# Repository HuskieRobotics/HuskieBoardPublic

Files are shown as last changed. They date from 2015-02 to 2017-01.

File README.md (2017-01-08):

# The Huskie Board
## Overview
The Huskie Board, designed by Team 3061, is an FRC qualified expansion board for the
NI roboRIO robotics controller. In addition to breaking out all available signals on the
MXP expansion port, this board uses a Parallax Propeller chip (8 symmetrical logical
cores with shared memory and peripheral access) to enable tasks such as advanced
data logging, on-field driver control and status, and NeoPixel control. Additional GPIO
and analog inputs are added with open source code to allow further customization.

## Firmware
The Huskie Board's firmware is stored on a 32 KB Flash chip. It can be upgraded over USB, and teams are welcome to load their own firmware. All Huskie Board firmware is stored in the `propeller firmware/` directory.

## roboRIO software
The LabView firmware is available in the `LabView/LabVIEW API/` directory. This includes examples in the `Examples/` folder, and the API source code in the `Huskie Board/` folder. See `install.txt` for more information.

Currently, the roboRIO API is only available for labview, though we hope to port it for C++ and Java soon.

## Hardware
The Huskie Board was designed in Eagle CAD, and sources are available in `Eagle CAD/projects/HuskieBoard/`.

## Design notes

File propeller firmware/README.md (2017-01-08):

# Huskie Board Firmware

---

### Language
The Huskie Board runs on the [Parallax Propeller microcontroller](https://www.parallax.com/catalog/microcontrollers/propeller/chips). The majority of our code is written in Spin, though there is some pasm (assembly) included. The development environment is available [here](https://www.parallax.com/downloads/propeller-tool-software-windows). 

---

### Object Heiarchy
* `main.spin`
  * `RR uart connection.spin`
    * `FASTSERIAL-080927.spin`
    * `adc124s021_x2.spin`
    * `Disabled Parallax Serial Terminal.spin`
    * `Serial_Lcd.spin`
      * `Simple_Serial.spin`
    * `LED Main.spin`
      * `Neopixel Driver.spin`
    * `SD Controller.spin`
      * `fsrw.spin`
        * `safe_spi.spin`
---
### File Descriptions

`Disabled Parallax Serial Terminal.spin` - Allows us to turn off the debugging software for release versions. `Parallax Serial Terminal.spin` can be used instead to enable debugging.

`FASTSERIAL-080927.spin` - Used to communicate with the RoboRio at a high baud rate.

`fsrw.spin` - FAT32 filesystem control for the SD card

`adc124s021_x2.spin` - Controls SPI communication with the onboard ADCs, as well as averaging of the ADC values.

`LED Main.spin` - Controls a strip of Neopixel LEDs on the robot. The patterns can be selected by the RoboRIO. More patterns can be added here.

`main.spin` - Top object file, initiates all processes. Also controls the 4 LEDs to indicate DIP switch positions.

`Neopixel Driver.spin` - Neopixel LED driver

`ProductionTesterWithMain.spin` - Used to test each Huskie Board on a custom fixture before shipping. This is technically what is on the Huskie Board when it is purchased, but if firmware needs to be reflashed by a user, they should flash `main.spin`.

`Propeller EEprom.spin` - Dependancy of `ProductionTesterWithMain.spin`, allows for saving data to the EEprom for permanent storage.

`RR uart connection.spin` - UART controller for connection between propeller and roboRIO

`safe_spi.spin` - SPI routines used for the SD card

`SD Controller.spin` - High level API for SD card control

`Serial_Lcd.spin` - High level interface for Parallax LCD displays

`Simple_Serial.spin` - A simple low baud rate serial object, for use with the LCD displays.
---

# How To Load Code
1. Run the Propeller Tool executable
2. Open "main.spin"
3. Compile and load to EEPROM (Run -> Compile Current -> Load EEPROM)

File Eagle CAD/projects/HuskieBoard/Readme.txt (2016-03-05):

Fab Drawing                    | Fab.pdf
Assy Drawing                   | Assy.pdf
Fab Array Drawing, no holes    | Fab_1x3A.pdf
Fab Array Drawing, with holes  | Fab_1x3B.pdf

Top Copper                     | RoboRIO Expansion Board V2.GTL
Bottom Copper                  | RoboRIO Expansion Board V2.GBL
Top Silkscreen                 | RoboRIO Expansion Board V2.GTO
Top Paste                      | RoboRIO Expansion Board V2.GTP
Top Soldermask                 | RoboRIO Expansion Board V2.GTS
Bottom Soldermask              | RoboRIO Expansion Board V2.GBS
Drill File                     | RoboRIO Expansion Board V2.TXT
Mill Layer                     | RoboRIO Expansion Board V2.GML

centroid file                  | RoboRIO Expansion Board V2_centroid.csv

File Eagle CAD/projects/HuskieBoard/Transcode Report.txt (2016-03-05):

   ---- Transcoding 'C:\Users\d_emge\Documents\GitHub\roborioExpansion\projects\RoboRio\RoboRioExpansionBoard\RoboRio Expansion Board V2.GTP' ----   Wed Feb 03 08:32:43 2016

D10   --> D356
D11   --> D357
D12   --> D358
D13   --> D359
D14   --> D360
D15   --> D361
D16   --> D362
D17   --> D363
D18   --> D364
D19   --> D365
D20   --> D366
D21   --> D367
D22   --> D368
D23   --> D369
D24   --> D370
D25   --> D371
D26   --> D372
D27   --> D373
D28   --> D374
D29   --> D375
D30   --> D376
D31   --> D377
-----------------------------------------------------------------

   ---- Transcoding 'C:\Users\d_emge\Documents\GitHub\roborioExpansion\projects\RoboRio\RoboRioExpansionBoard\RoboRio Expansion Board V2.GTS' ----   Wed Feb 03 08:32:43 2016

D10   --> D378
D11   --> D379
D12   --> D380
D13   --> D381
D14   --> D382
D15   --> D383
D16   --> D384
D17   --> D385
D18   --> D386
D19   --> D387
D20   --> D388
D21   --> D389
D22   --> D390
D23   --> D391
D24   --> D392
D25   --> D393
D26   --> D394
D27   --> D395
D28   --> D396
D29   --> D397
D30   --> D398
D31   --> D399
D32   --> D400
D33   --> D401
D34   --> D402
D35   --> D403
D36   --> D404
D37   --> D405
D39   --> D406
D40   --> D407
D41   --> D408
-----------------------------------------------------------------

   ---- Transcoding 'C:\Users\d_emge\Documents\GitHub\roborioExpansion\projects\RoboRio\RoboRioExpansionBoard\RoboRio Expansion Board V2.GTL' ----   Wed Feb 03 08:32:43 2016

D10   --> D409
D11   --> D410
D12   --> D411
D13   --> D412
D14   --> D413
D15   --> D414
D16   --> D415
D17   --> D416
D18   --> D417
D19   --> D418
D20   --> D419
D21   --> D420
D22   --> D421
D23   --> D422
D24   --> D423
D25   --> D424
D26   --> D425
D27   --> D426
D28   --> D427
D29   --> D428
D30   --> D429
D31   --> D430
D32   --> D431
D33   --> D432
D34   --> D433
D35   --> D434
D36   --> D435
D37   --> D436
D39   --> D437
D40   --> D438
D41   --> D439
D42   --> D440
D43   --> D441
D44   --> D442
D45   --> D443
D46   --> D444
D47   --> D445
D48   --> D446
D49   --> D447
D50   --> D448
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
-----------------------------------------------------------------

   ---- Transcoding 'C:\Users\d_emge\Documents\GitHub\roborioExpansion\projects\RoboRio\RoboRioExpansionBoard\RoboRio Expansion Board V2.GBL' ----   Wed Feb 03 08:32:43 2016

D11   --> D451
D12   --> D452
D13   --> D453
D14   --> D454
D15   --> D455
D16   --> D456
D17   --> D457
D18   --> D458
D19   --> D459
D20   --> D460
D21   --> D461
D22   --> D462
D23   --> D463
D24   --> D464
-----------------------------------------------------------------

   ---- Transcoding 'C:\Users\d_emge\Documents\GitHub\roborioExpansion\projects\RoboRio\RoboRioExpansionBoard\RoboRio Expansion Board V2.GBS' ----   Wed Feb 03 08:32:43 2016

D10   --> D465
D11   --> D466
D12   --> D467
D13   --> D468
D14   --> D469
D15   --> D470
D16   --> D471
D17   --> D472
D18   --> D473
-----------------------------------------------------------------

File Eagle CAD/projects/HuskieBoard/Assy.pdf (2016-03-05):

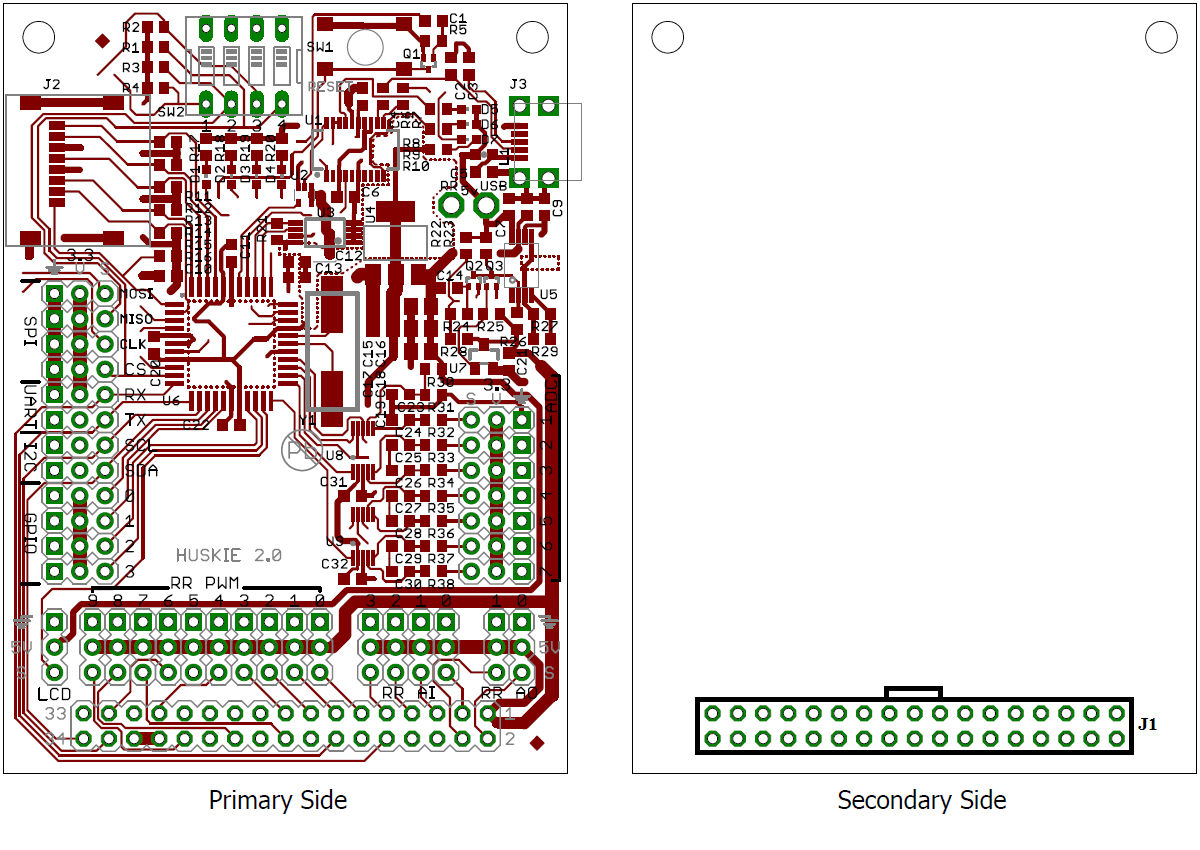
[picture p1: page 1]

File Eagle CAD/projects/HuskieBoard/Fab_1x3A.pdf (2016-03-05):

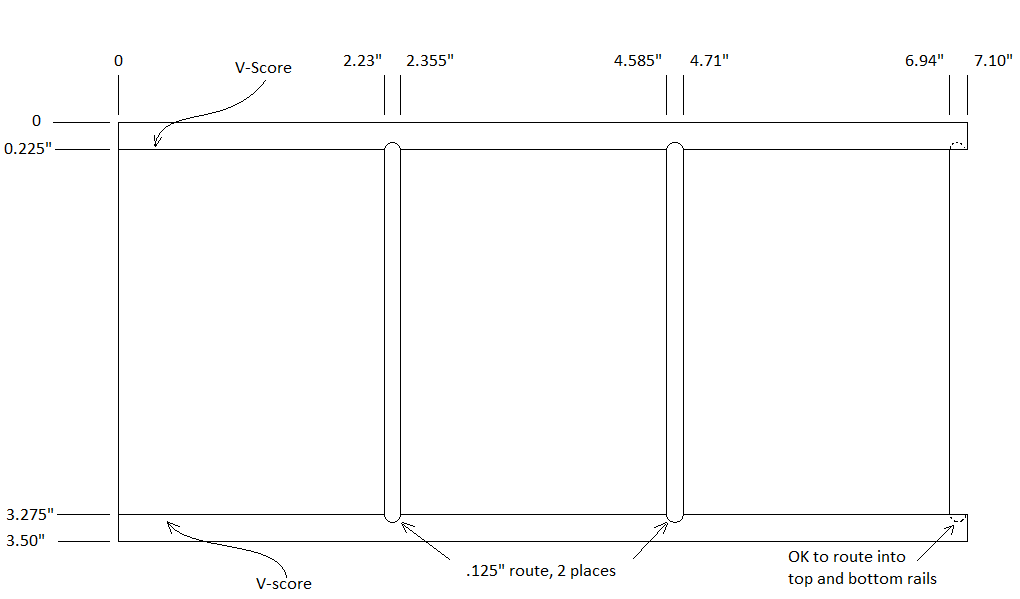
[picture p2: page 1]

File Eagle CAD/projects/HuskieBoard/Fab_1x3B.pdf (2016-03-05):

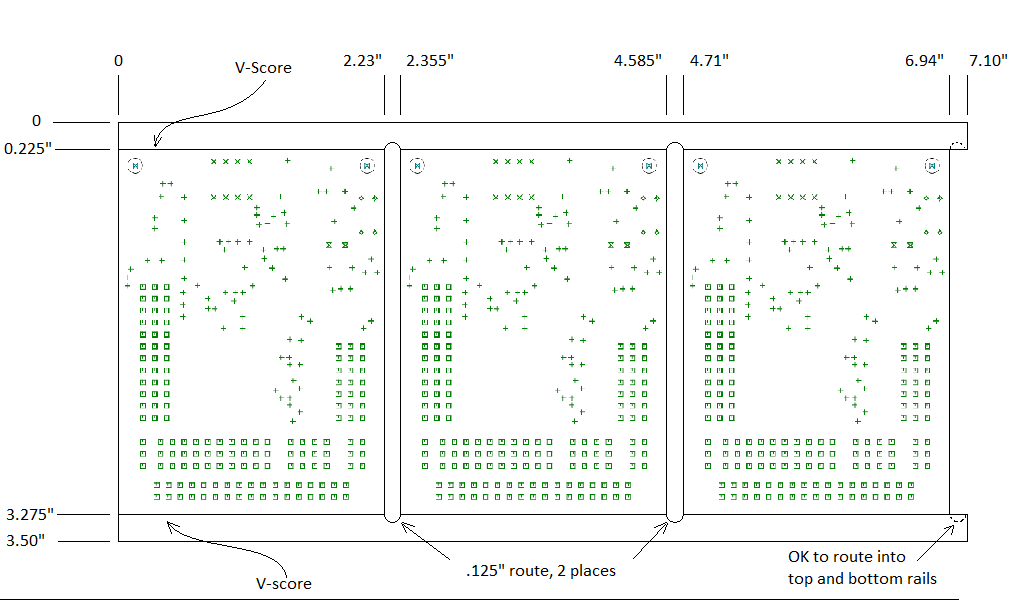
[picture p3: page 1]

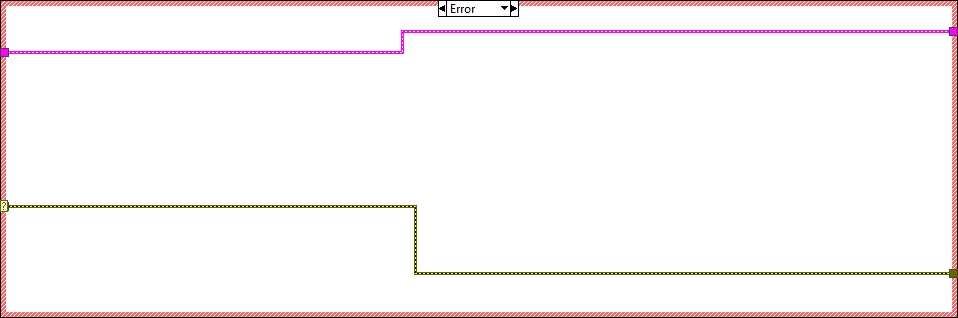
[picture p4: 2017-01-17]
LabView/LabVIEW API/Huskie Board/HuskieBoard API Doc/HB_GetFirmwareVersion/HB__GetFirmwareVersiond2.png

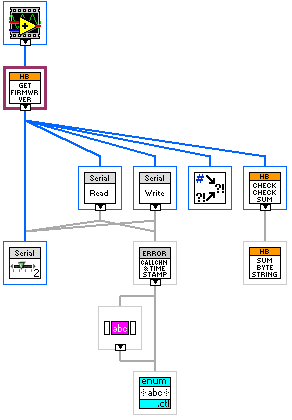
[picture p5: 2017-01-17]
LabView/LabVIEW API/Huskie Board/HuskieBoard API Doc/HB_GetFirmwareVersion/HB__GetFirmwareVersionh.png

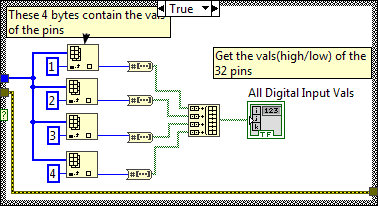
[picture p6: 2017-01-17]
LabView/LabVIEW API/Huskie Board/HuskieBoard API Doc/HB_ReadDIOAllChannels/HB__ReadDIOAllChannelsd1.png

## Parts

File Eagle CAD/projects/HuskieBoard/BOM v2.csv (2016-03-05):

Qty | Value | Device | Package | Parts | Description | MF | MPN | OC_FARNELL | OC_NEWARK | TP_SIGNAL_NAME
12 |  | 3PINDEVICEDEFAULT | 3PINPACKAGE | J4, J5, J6, J7, J11, J17, J18, J19, J20, J21, J22, J23
1 |  | SW_DIP-4 | EDG-04 | SW1 | DIP SWITCH
7 | .1uF | C-EUC0603K | C0603K | C1, C2, C3, C6, C10, C13, C17 | CAPACITOR, European symbol
8 | 0.1uF | C-EUC0603K | C0603K | C14, C15, C16, C19, C21, C22, C23, C24 | CAPACITOR, European symbol
18 | 10k | R-US_R0603 | R0603 | R1, R3, R6, R7, R8, R15, R16, R17, R18, R19, R23, R29, R30, R31, R32, R33, R34, R35 | RESISTOR, American symbol
6 | 10uF | C-EUC0805K | C0805K | C4, C5, C7, C11, C12, C20 | CAPACITOR, European symbol
3 | 1k | R-US_R0603 | R0603 | R5, R13, R14 | RESISTOR, American symbol
3 | 1uF | C-EUC0603K | C0603K | C8, C9, C18 | CAPACITOR, European symbol
5 | 220 | R-US_R0603 | R0603 | R4, R9, R10, R11, R12 | RESISTOR, American symbol
1 | 24LC256ST | 24LC128ST | TSSOP8 | U2 | Serial EEPROM | MICROCHIP | 24LC128-I/ST | 1296573 | 62K0578
8 | 270 | R-US_R0603 | R0603 | R2, R20, R21, R22, R24, R25, R26, R28 | RESISTOR, American symbol
1 | 33k | R-US_R0603 | R0603 | R27 | RESISTOR, American symbol
1 | 51387-0578 | USBMINIB | USB-MINIB | J3 | USB Connectors
2 | ADC124S01 | ADC124S01 | ADC124S021VSSOP | U$1, U$2
1 | AI0 | 3PINDEVICEDEFAULT | 3PINPACKAGE | J35
1 | AI1 | 3PINDEVICEDEFAULT | 3PINPACKAGE | J36
1 | AI2 | 3PINDEVICEDEFAULT | 3PINPACKAGE | J37
1 | AI3 | 3PINDEVICEDEFAULT | 3PINPACKAGE | J38
1 | AO0 | 3PINDEVICEDEFAULT | 3PINPACKAGE | J39
1 | AO1 | 3PINDEVICEDEFAULT | 3PINPACKAGE | J40
1 | BLUE | LEDCHIPLED_0603 | CHIPLED_0603 | D6 | LED
1 | BUTTON | BUTTON | RESETBUTTON300000MILLION | S1
1 | FT232RL | FT232RL | SSOP28 | U3 | Source: http://www.ftdichip.com/Documents/DataSheets/DS_FT232R_v104.pdf |  | FT232RL | 1146032 | 91K9918
2 | GREEN | LEDCHIPLED_0603 | CHIPLED_0603 | D1, D4 | LED
1 | HC\49USCRYSTAL | HC\49USCRYSTAL | HC\49US | Y1
1 | I2C_SCL | 3PINDEVICEDEFAULT | 3PINPACKAGE | J12
1 | I2C_SDA | 3PINDEVICEDEFAULT | 3PINPACKAGE | J13
1 | LCD | 3PINDEVICEDEFAULT | 3PINPACKAGE | J16
1 | MICROSD-HINGED | MICROSD-HINGED | MICRO_SD_HINGED_TYPE | J2
3 | NPN-SOT416 | NPN-SOT416 | SC75_INFINEON | Q1, Q2, Q3
1 | P8X32A-Q44_P | P8X32A-Q44_P | P8X32A-Q44 | U1
1 | PWM0 | 3PINDEVICEDEFAULT | 3PINPACKAGE | J25
1 | PWM1 | 3PINDEVICEDEFAULT | 3PINPACKAGE | J26
1 | PWM2 | 3PINDEVICEDEFAULT | 3PINPACKAGE | J27
1 | PWM3 | 3PINDEVICEDEFAULT | 3PINPACKAGE | J28
1 | PWM4 | 3PINDEVICEDEFAULT | 3PINPACKAGE | J29
1 | PWM5 | 3PINDEVICEDEFAULT | 3PINPACKAGE | J30
1 | PWM6 | 3PINDEVICEDEFAULT | 3PINPACKAGE | J31
1 | PWM7 | 3PINDEVICEDEFAULT | 3PINPACKAGE | J32
1 | PWM8 | 3PINDEVICEDEFAULT | 3PINPACKAGE | J33
1 | PWM9 | 3PINDEVICEDEFAULT | 3PINPACKAGE | J34
2 | RED | LEDCHIPLED_0603 | CHIPLED_0603 | D3, D5 | LED
1 | REG1117 | REG1117 | SOT223 | U7 | 800mA and 1A Low Dropout (LDO) Positive Regulator |  | AP1117 | 1097566 | 14P6981
1 | RRINTERFACE-FEMALE | RRINTERFACE-FEMALE | RRINT-FEMALE | J1
1 | SPI_CLK | 3PINDEVICEDEFAULT | 3PINPACKAGE | J9
1 | SPI_CS | 3PINDEVICEDEFAULT | 3PINPACKAGE | J8
1 | SPI_MISO | 3PINDEVICEDEFAULT | 3PINPACKAGE | J10
1 | TC54-CB | TC54-CB | SOT23 | U4 | Microchip TC54 Voltage Detector
2 | TPPAD1-17 | TPPAD1-17 | P1-17 | TP_5V-RR, TP_5V-USB | Test pad
1 | TPS2115APWR | TPS2115APWR | TSSOP-8 | U6
1 | TP_GND | 3PINDEVICEDEFAULT | 3PINPACKAGE | J24
1 | UART_RX | 3PINDEVICEDEFAULT | 3PINPACKAGE | J15
1 | UART_TX | 3PINDEVICEDEFAULT | 3PINPACKAGE | J14
1 | YELLOW | LEDCHIPLED_0603 | CHIPLED_0603 | D2 | LED

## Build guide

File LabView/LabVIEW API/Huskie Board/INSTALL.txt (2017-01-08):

Huskie Board LabVIEW SDK Installation Instructions

The installer for the Huskie Board LabVIEW SDK is coming soon. In the
	meantime, the SDK has to be installed manually.

1. Unzip the downloaded zip file.
2. Copy the Huskie Board folder into the vi.lib\Rock
	Robotics\WPI\ThirdParty\Sensors folder in the LabVIEW 2016
	folder. By default, the full path is C:\Program Files\National
	Instruments\LabVIEW 2016\vi.lib\Rock
	Robotics\WPI\ThirdParty\Sensors\
3. Copy the HB-errors.txt file into the user.lib\errors folder in the
	LabVIEW 2016 folder. By default, the full path is C:\Program
	Files\National Instruments\LabVIEW
	2016\user.lib\errors\HB-errors.txt
4. The Examples folder may be copied anywhere that is convenient.

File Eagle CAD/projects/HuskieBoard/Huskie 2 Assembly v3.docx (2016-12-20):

# Huskie 2.0

# Assembly Instructions

# Version 3, 4/26/2016

Assembly Instructions Version | Date | Changed by | Reason for change
1 | 2/8/2016 | D. Emge | Original, prototype build
2 | x | x | Intentionally skipped to sync assy and BOM versions
3 | 4/26/2016 | D. Emge | Fix power supply oscillation, pilot build. Add section 5, rework instructions for converting from version1 to version 3.

1. General Information
  1.1. This is a lead-free assembly.
2. Surface Mount Assembly

Please reference Figure 1.

  2.1. The following parts are not installed:
- C14, C15, C17
  2.2. LEDs D1 through D4 are installed with Anodes at the bottom and Cathodes at the top. Cathodes are marked with a silkscreen dot.
  2.3. LEDs D5 through D7 are installed with Anodes on the right and Cathodes on the left.

Cathodes are marked with a silkscreen dot.

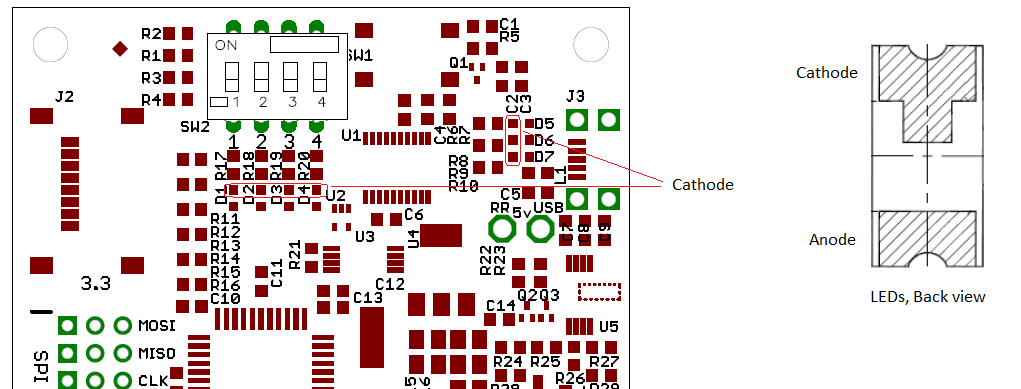
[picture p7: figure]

Figure 1, SW2 and LED Orientation

3. PTH Assembly – Primary Side
  3.1. SW2 is installed with the orientation shown in Figure 1, above, with the switch numbering aligned with the board’s silkscreen number markings.
  3.2. Header pins are arranged in sets of 3. Pins must be parallel in final assembly to allow proper connection of individual 3-pin mating connectors (each square pin is pin 1 of a 3-pin connection). Use a jig if necessary to maintain parallelism.

There are qyt 3 36-pin header strips on the BOM. They are separated into smaller headers as follows for installation on the PCB.

    3.2.1. Header strip 1: Separate into qty 3 12-pin strips and install in Location

A

    3.2.2. Header strip 2:
- Separate into qty 3 10-pin headers and install in Location

B

- Separate the remainder into qty 2 3-pin headers and install in location

C

    3.2.3. Header strip 3:
- Separate into qty 3 7-pin headers and install in Location

D

- Separate from the remainder qty 3 4-pin headers and install in Location

E

- Install the remaining 1x3 pin header into Location

F

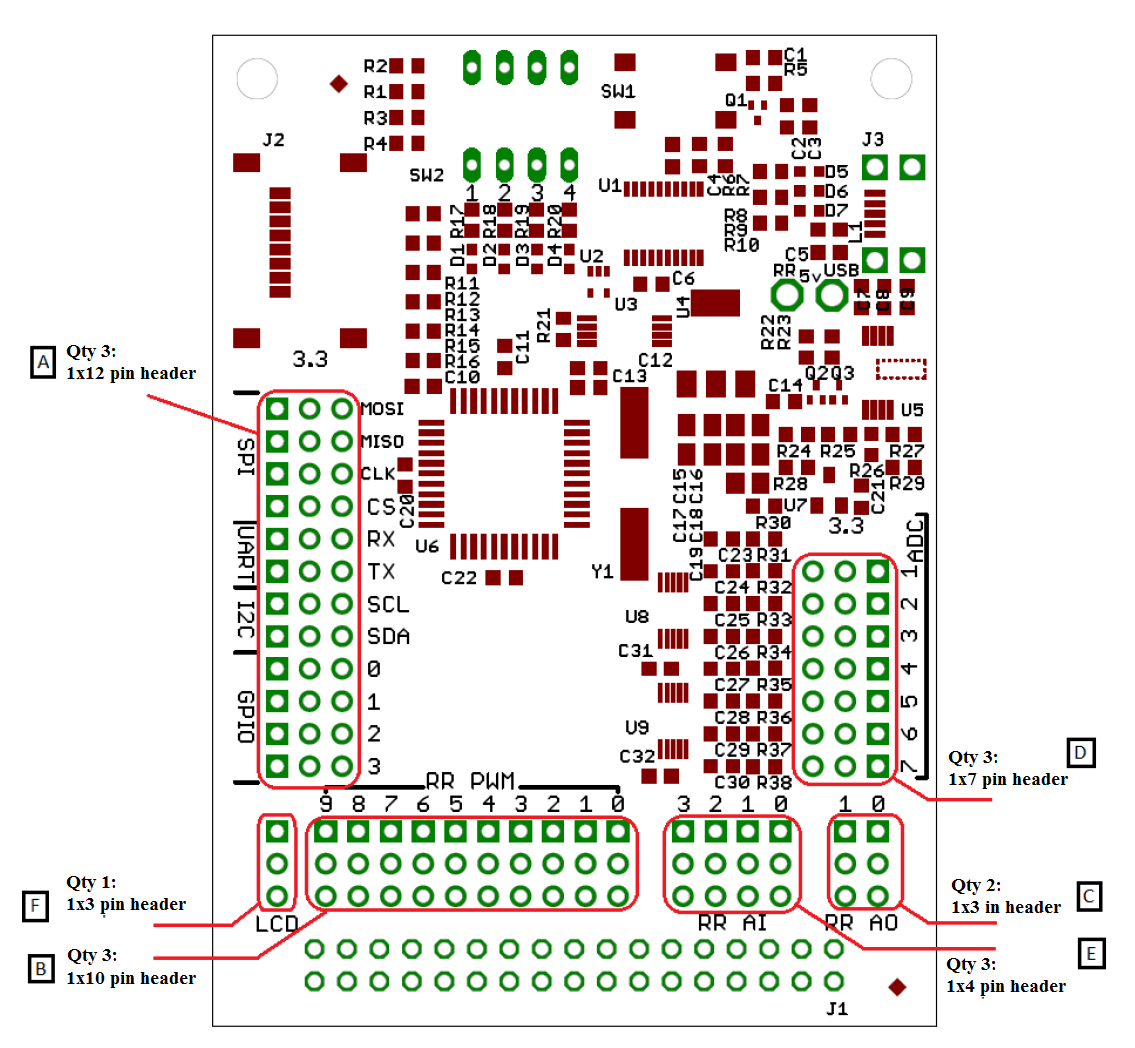
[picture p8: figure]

Figure 2, Header Placement

4. PTH Assembly – Secondary Side

J1 is installed on the secondary with the key oriented as shown below. It must be installed perpendicular to and flush with the PCB.

5. Rework Instructions, Version 1 to Version 3

For new builds, ignore this section.

  5.1. Remove capacitors C15 and C17.
  5.2. Remove U4 and replace with device indicated on BOM version 3.

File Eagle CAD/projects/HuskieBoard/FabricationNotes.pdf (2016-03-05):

1. Material
1.1. All material to be RoHS compliant.
1.2. All material to be tolerant of Pb-free solder process temperatures.
1.3. All material, including solder mask and legends, shall have a UL flammability rating of 94V-0. Date code and manufacturers UL symbol/type shall be permanently marked or etched on the board.
2. Solder Mask
2.1. Solder mask both sides, with blue color.
2.2. Encroach primary side via pads but prevent solder mask in via holes.
2.3. No solder mask on secondary side via pads.
2.4. No solder mask on component pads
2.5. Solder mask must be present between adjacent SMT pads.
3. Silkscreen
3.1. No silkscreen allowed on exposed lands or in holes.

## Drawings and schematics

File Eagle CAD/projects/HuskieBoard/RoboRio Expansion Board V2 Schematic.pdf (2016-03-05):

# CBUS3 19 CBUS2 10 CBUS1 17 CBUS0 18 RI 5 DCD 8 DSR 7 DTR 1 CTS 9 RTS 2

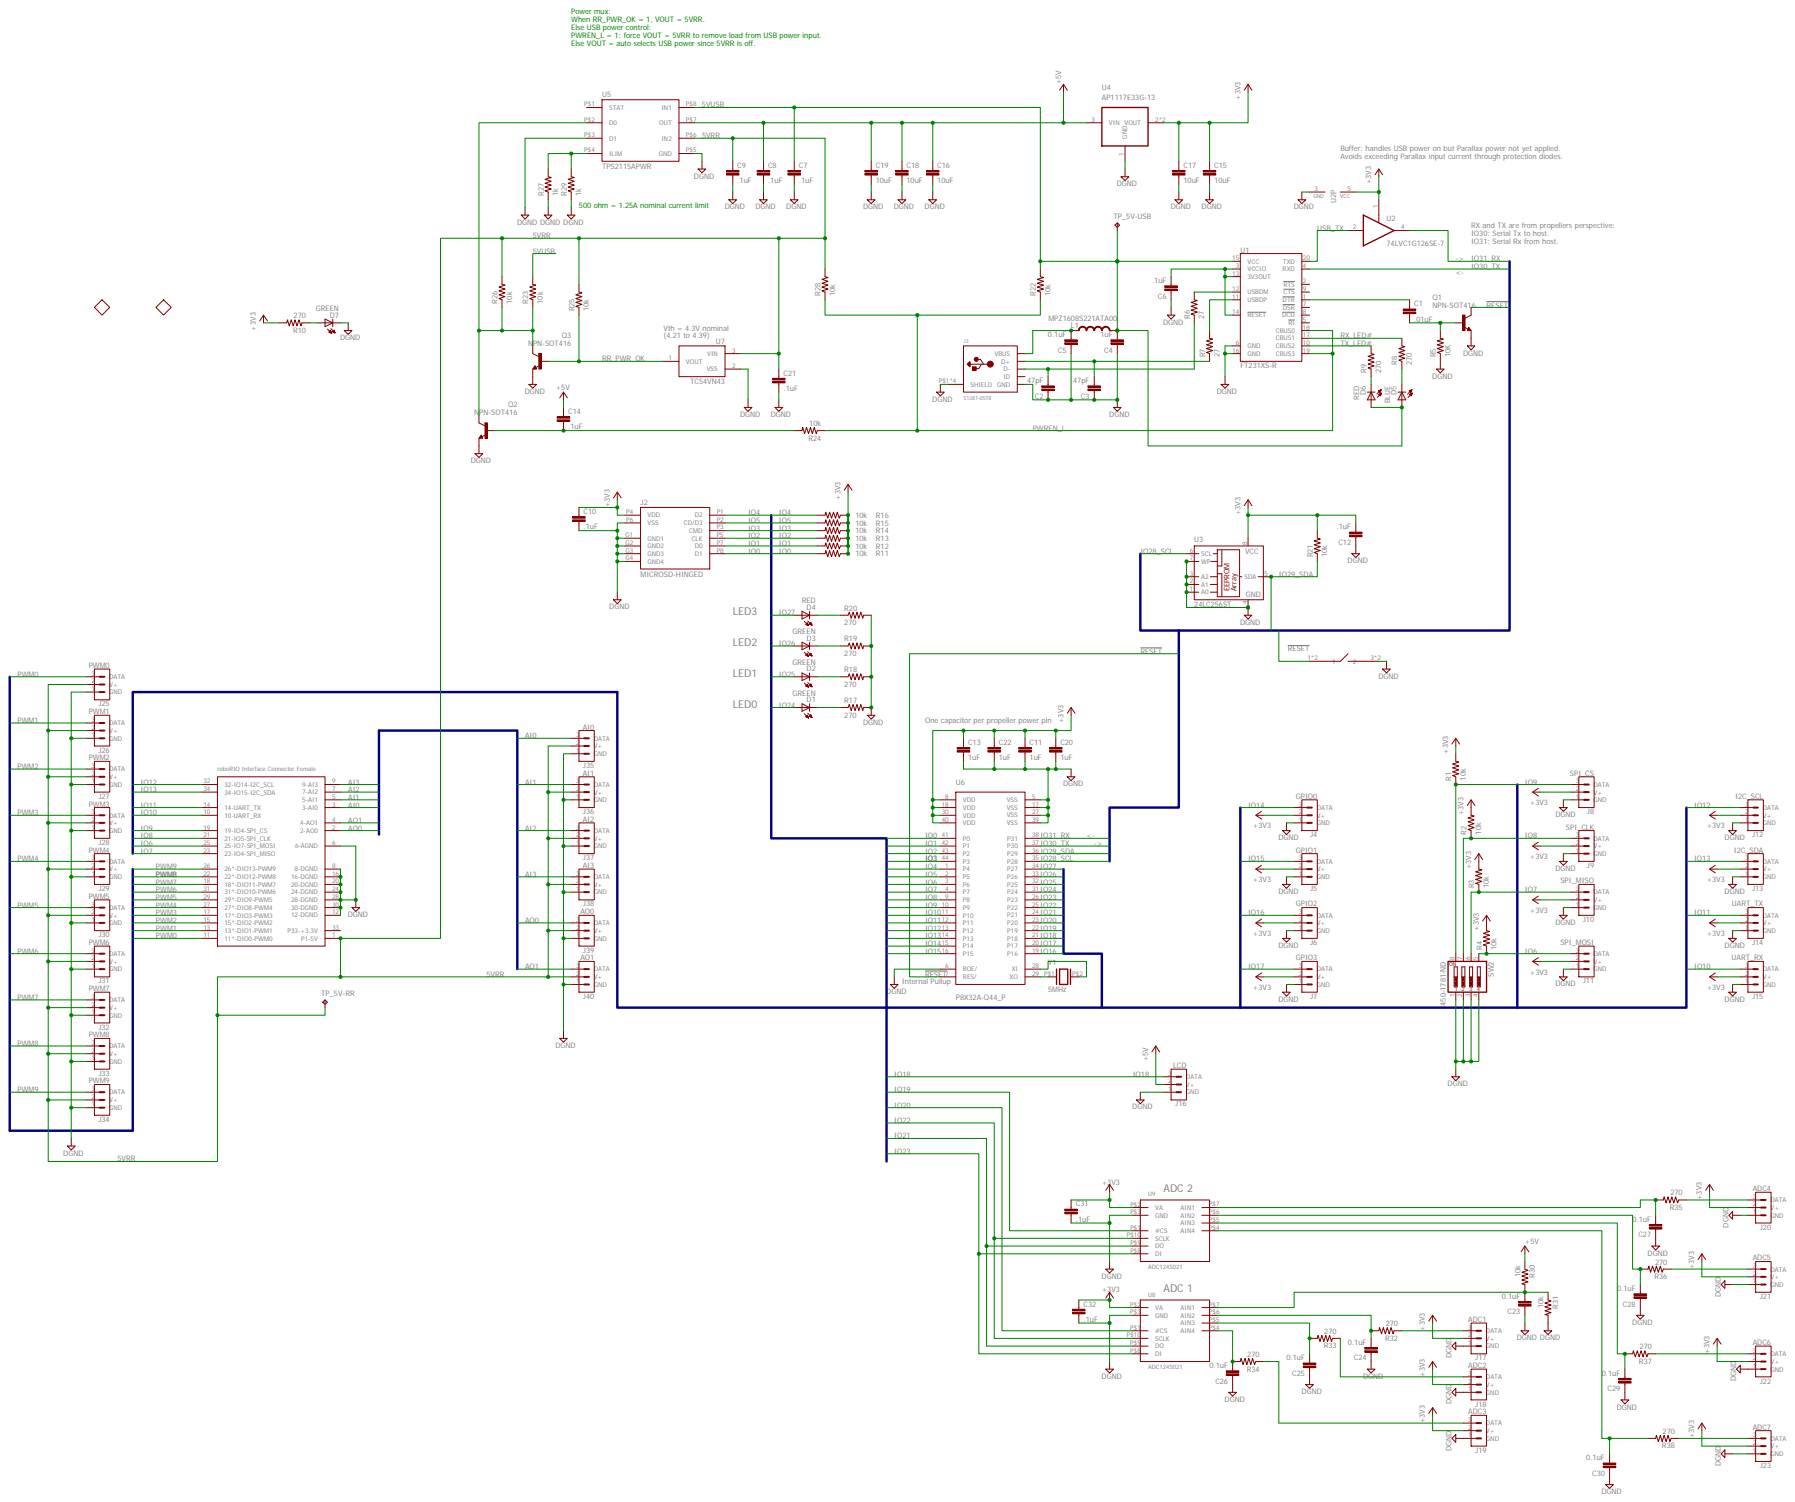
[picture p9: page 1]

Power mux:
When RR_PWR_OK = 1, VOUT = 5VRR.
Else USB power control:
PWREN_L = 1: force VOUT = 5VRR to remove load from USB power input.
Else VOUT = auto selects USB power since 5VRR is off.

Buffer: handles USB power on but Parallax power not yet applied.
Avoids exceeding Parallax input current through protection diodes.

500 ohm = 1.25A nominal current limit

RX and TX are from propellers perspective:
IO30: Serial Tx to host.
IO31: Serial Rx from host.

One capacitor per propeller power pin

roboRIO Interface Connector Female

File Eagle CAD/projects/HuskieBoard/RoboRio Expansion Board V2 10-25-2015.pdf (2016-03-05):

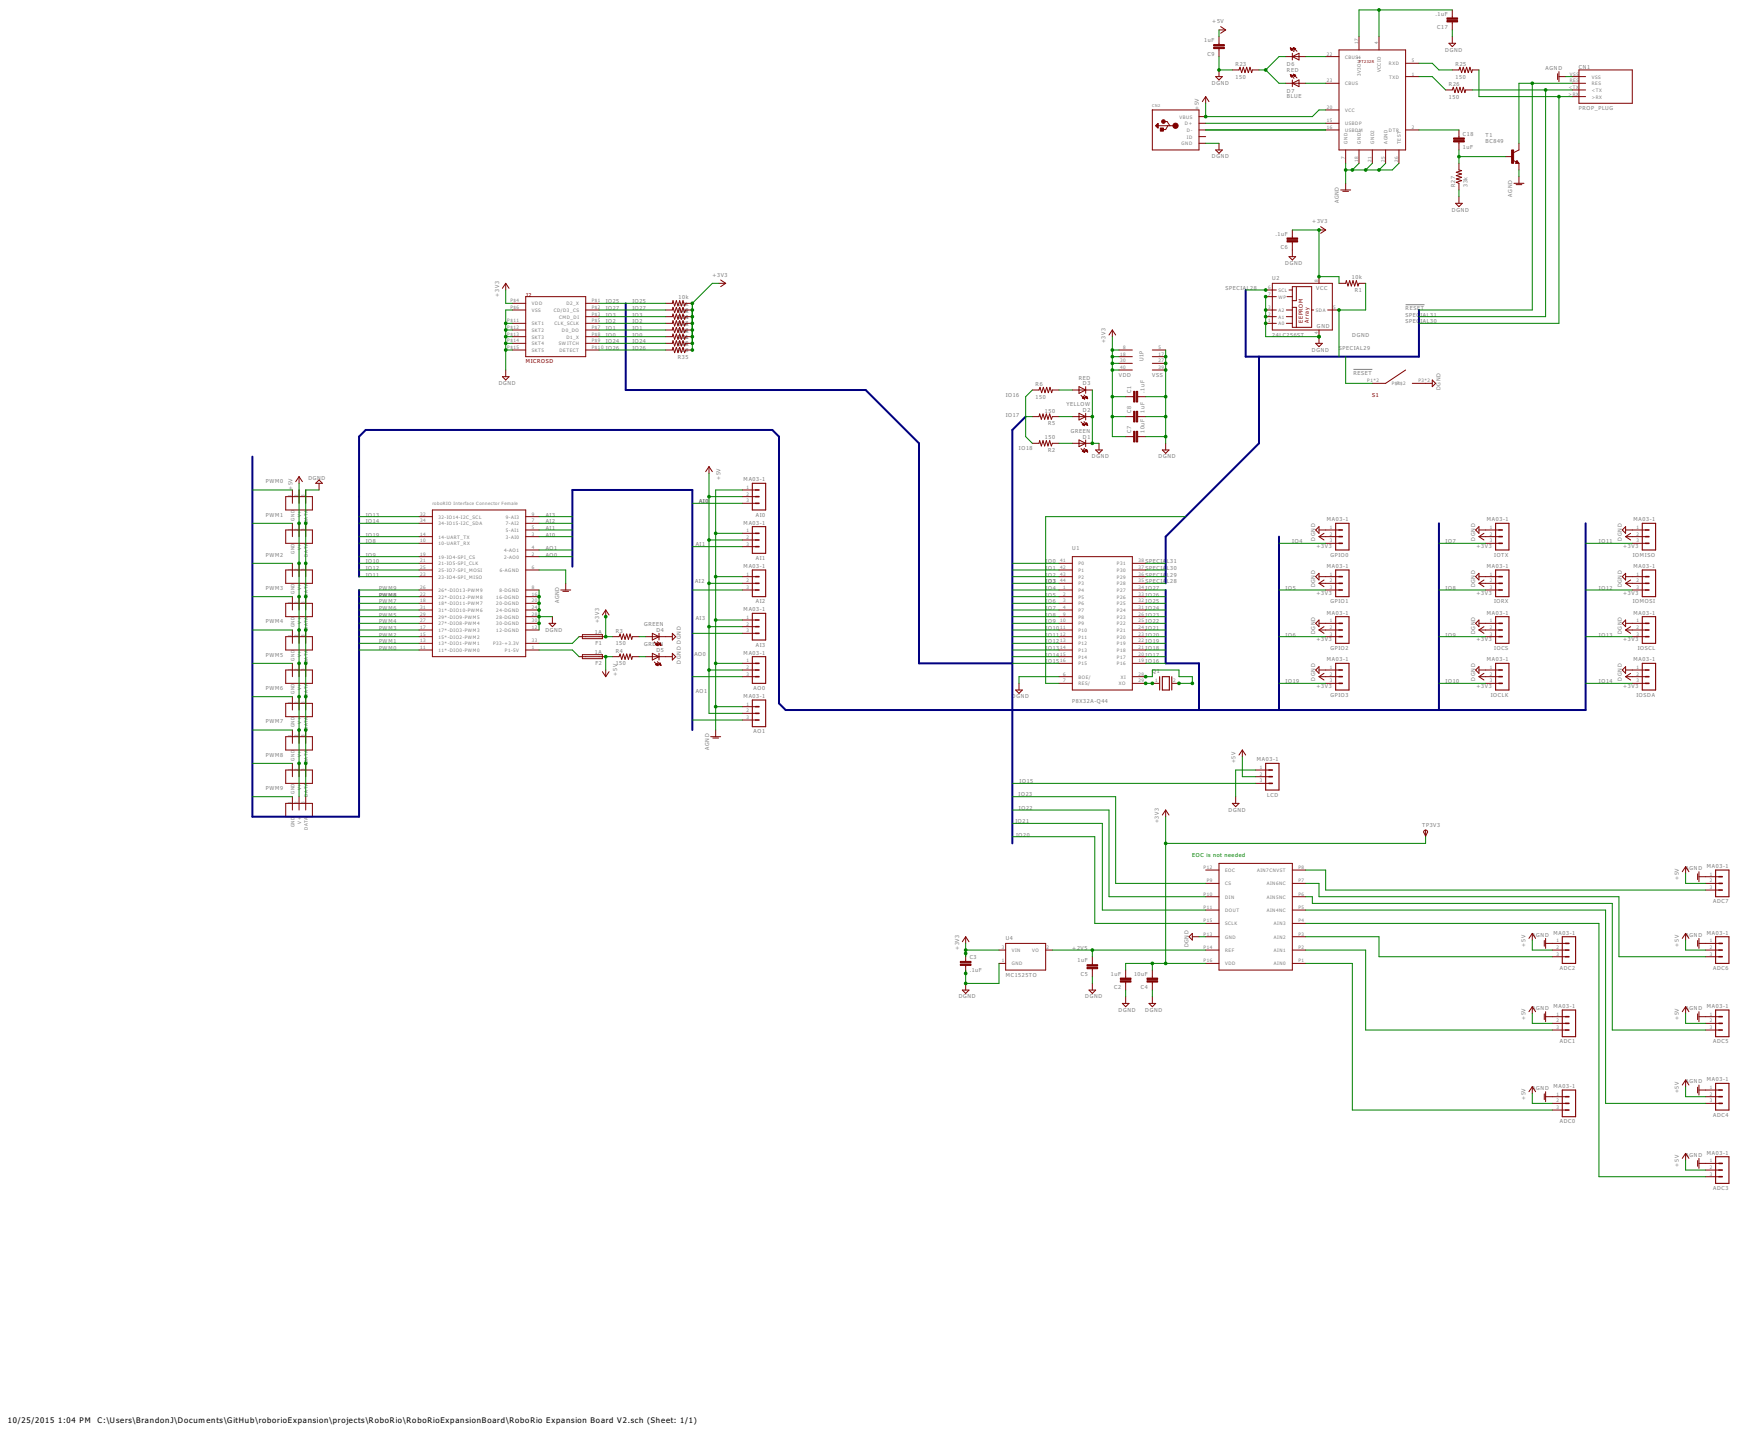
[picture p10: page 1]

roboRIO Interface Connector Female

EOC is not needed

10/25/2015 1:04 PM C:\Users\BrandonJ\Documents\GitHub\roborioExpansion\projects\RoboRio\RoboRioExpansionBoard\RoboRio Expansion Board V2.sch (Sheet: 1/1)

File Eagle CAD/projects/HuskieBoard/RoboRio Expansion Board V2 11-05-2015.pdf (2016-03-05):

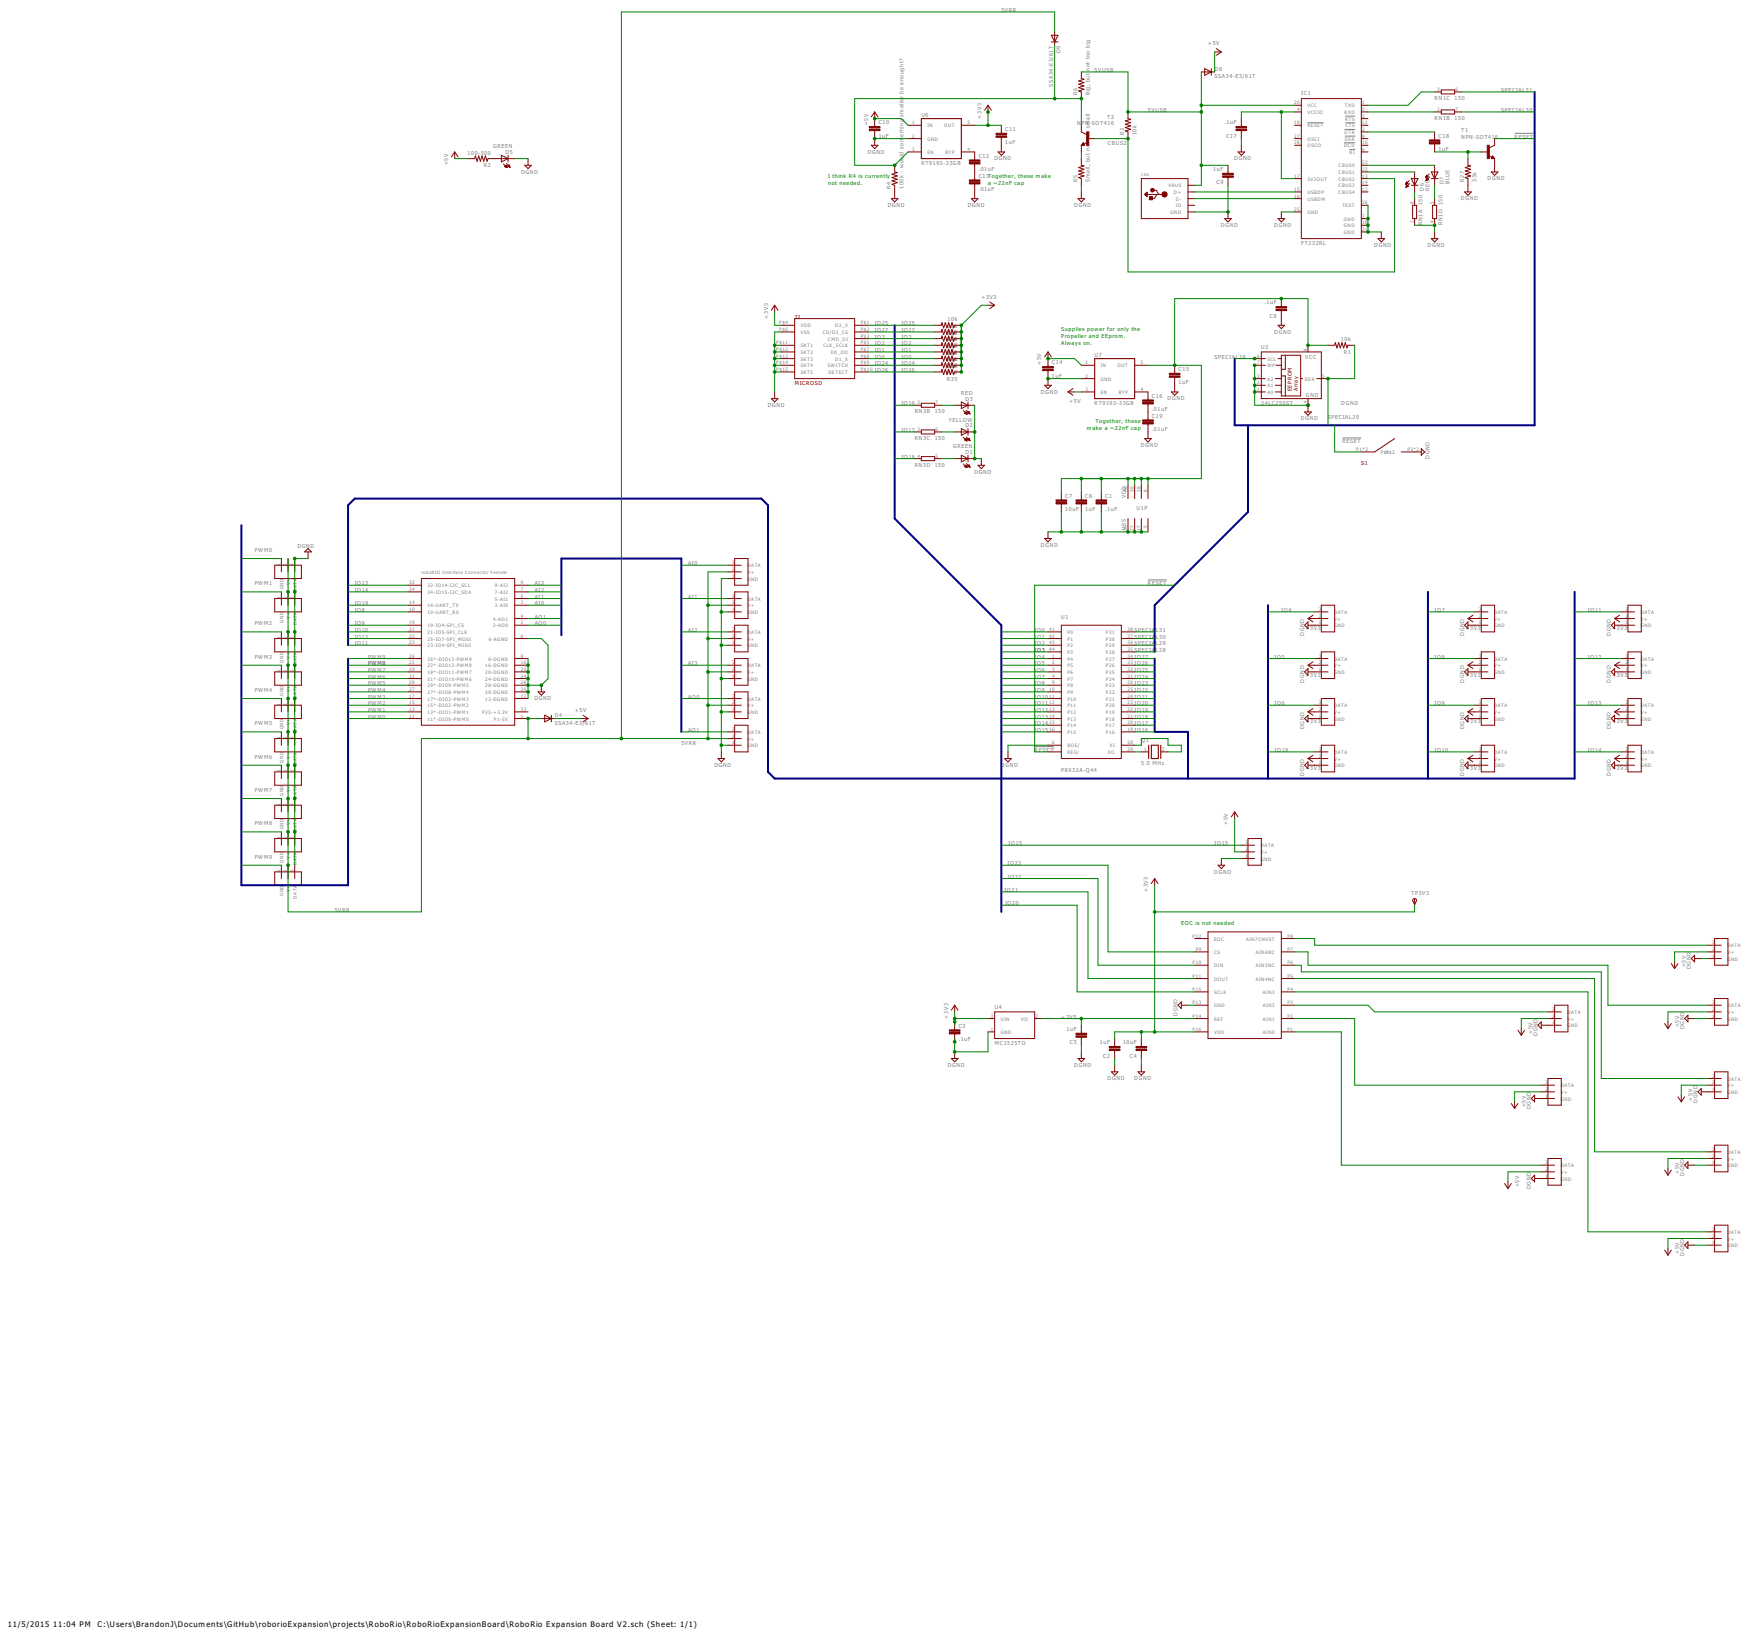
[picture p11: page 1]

SSA34-E3/61T Big, but not too big

100k - would something smaller be enought? DGND

Small, but not too small
NPN-SOT416

I think R4 is currently not needed.

Supplies power for only the Propeller and EEprom. Always on.

Together, these make a ~22nF cap

roboRIO Interface Connector Female

+3V3 DGND +3V3 DGND

EOC is not needed

11/5/2015 11:04 PM C:\Users\BrandonJ\Documents\GitHub\roborioExpansion\projects\RoboRio\RoboRioExpansionBoard\RoboRio Expansion Board V2.sch (Sheet: 1/1)

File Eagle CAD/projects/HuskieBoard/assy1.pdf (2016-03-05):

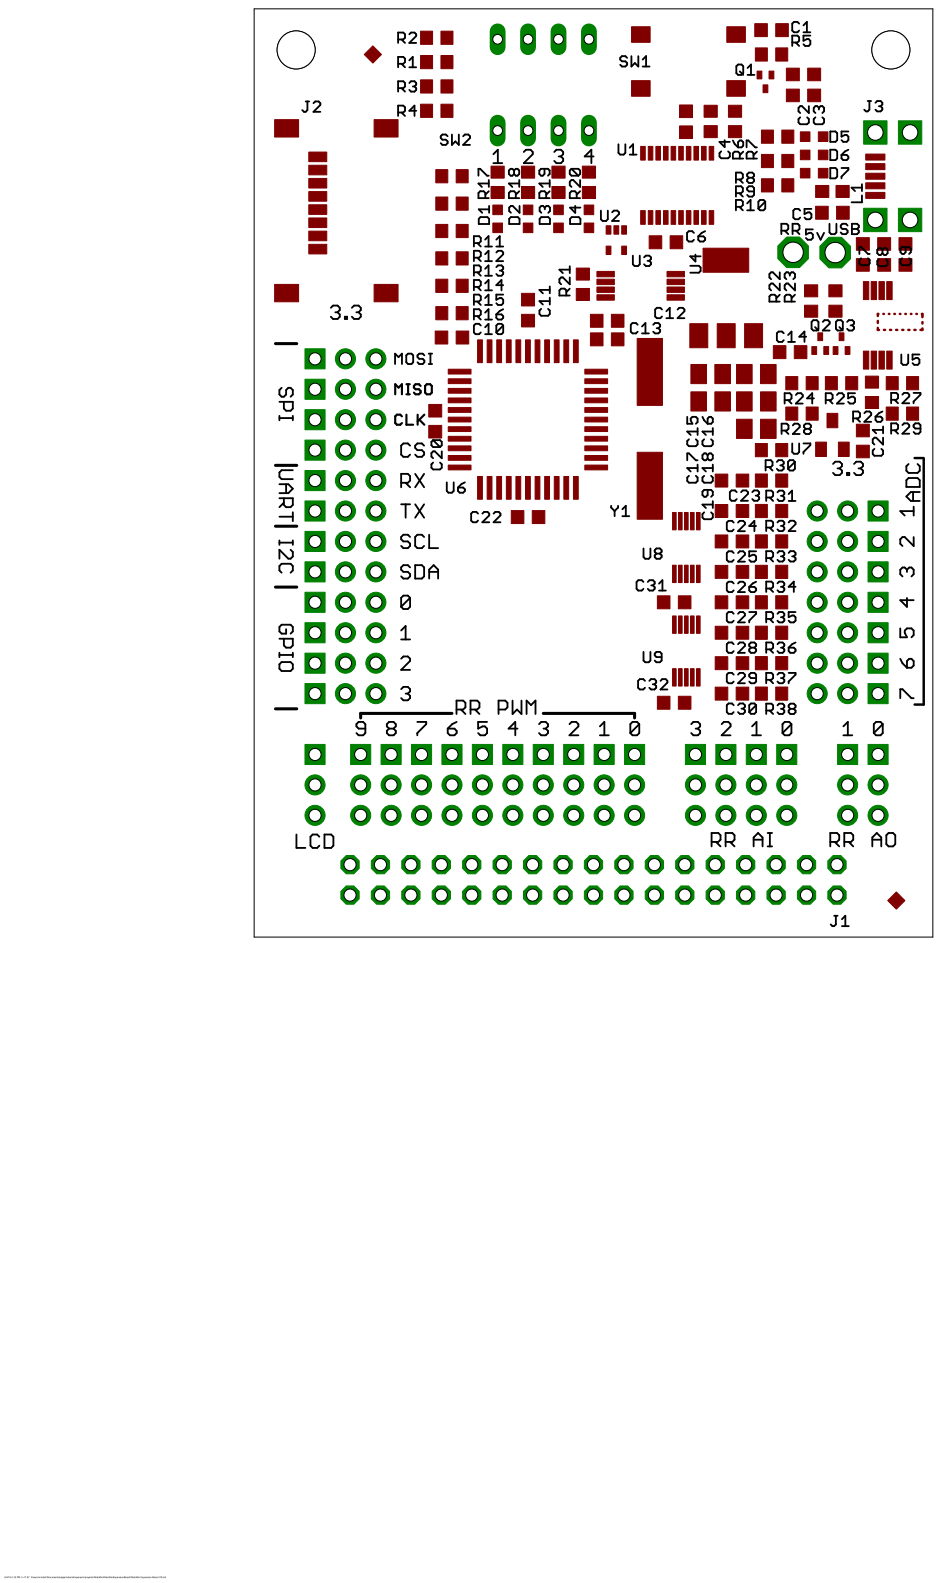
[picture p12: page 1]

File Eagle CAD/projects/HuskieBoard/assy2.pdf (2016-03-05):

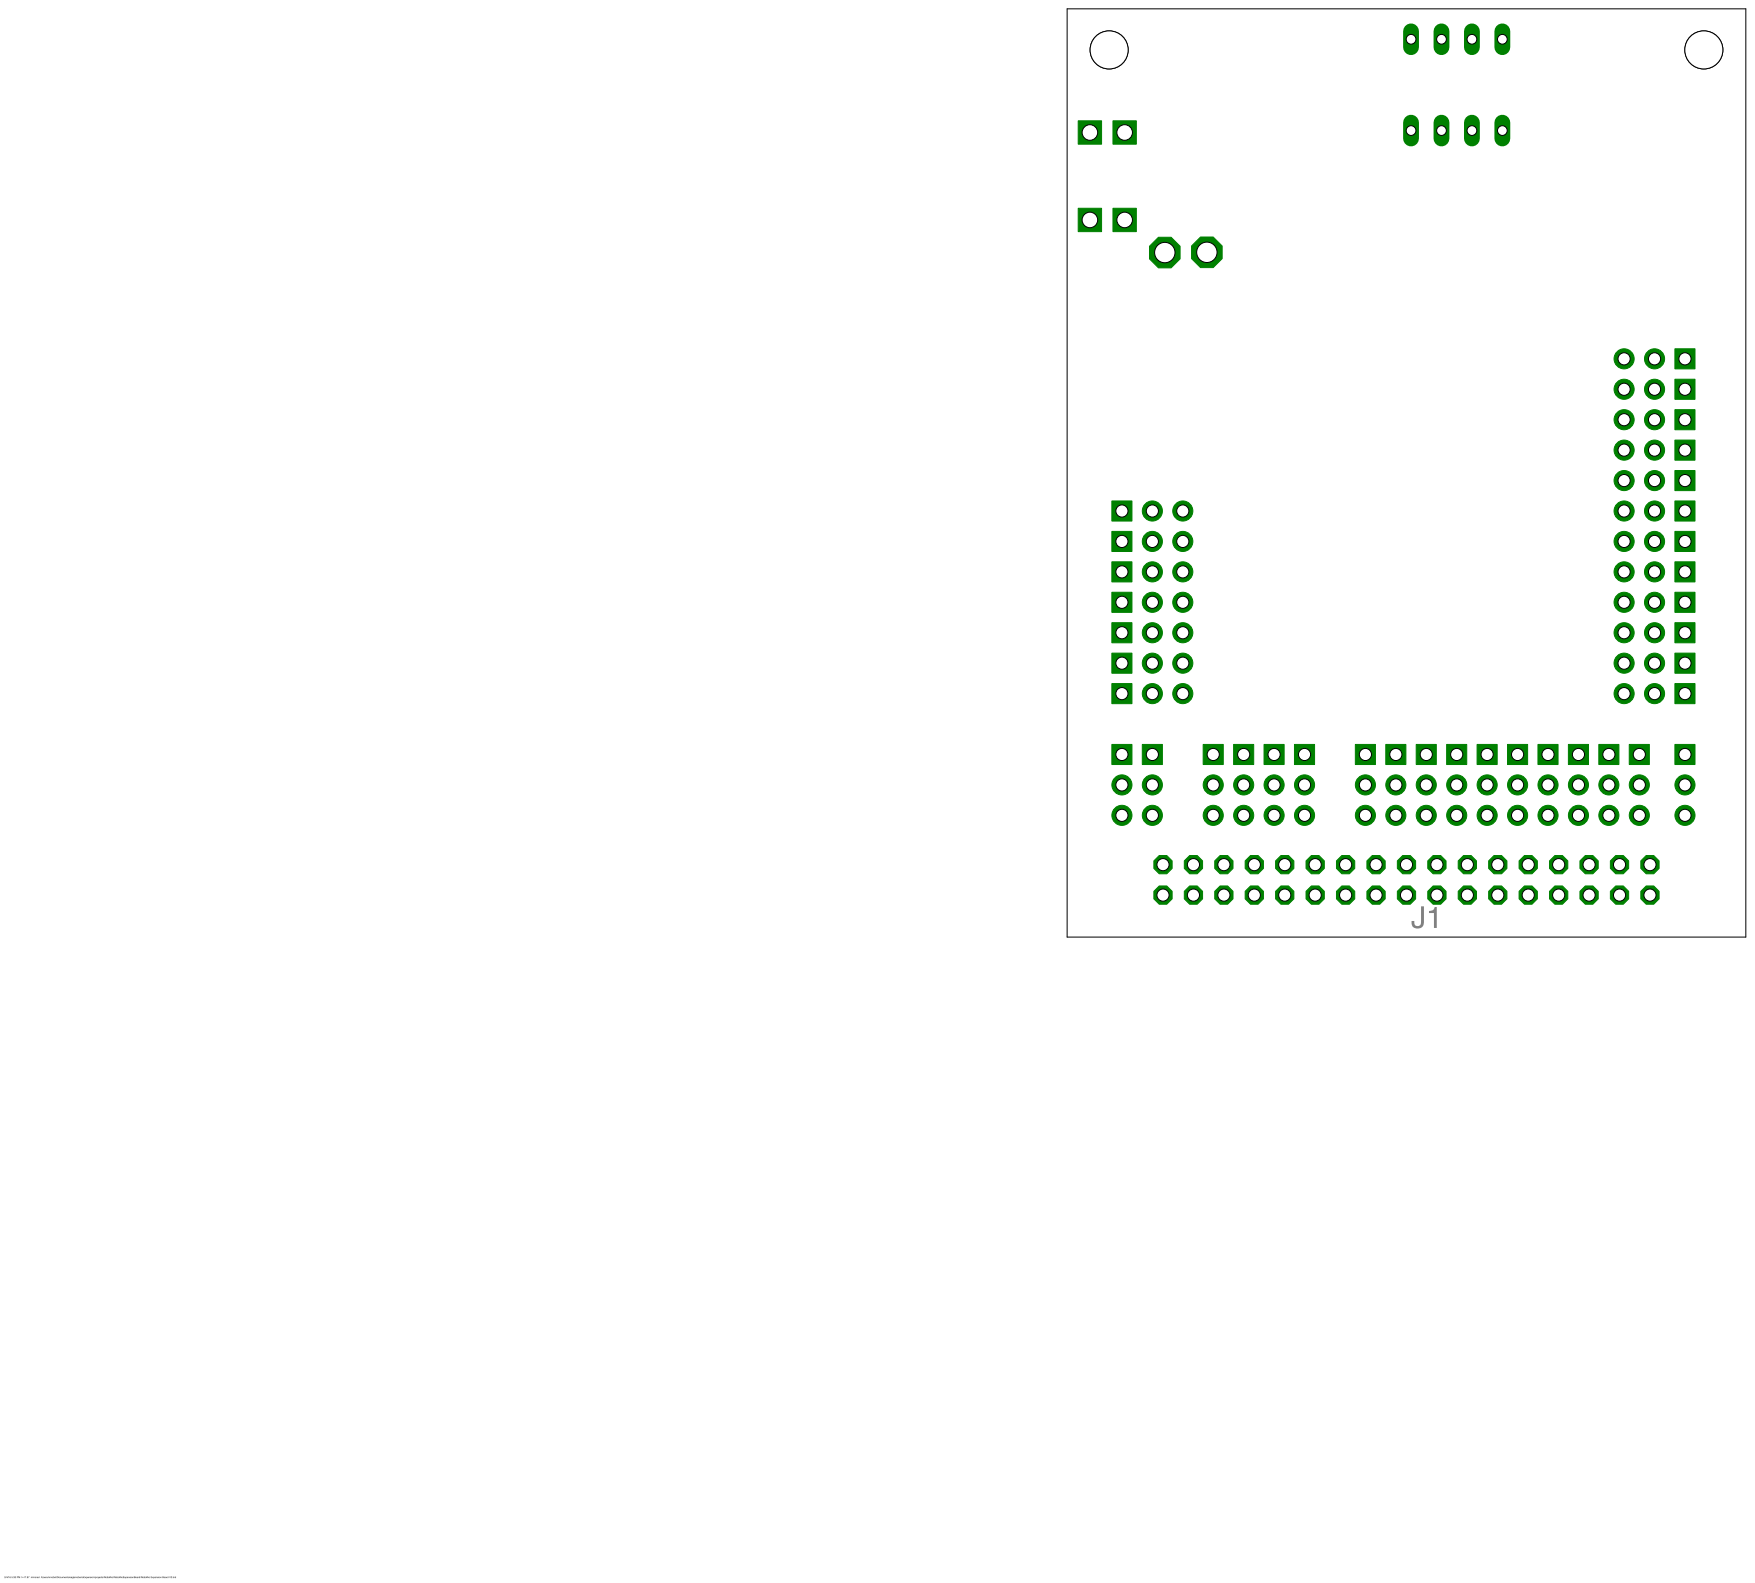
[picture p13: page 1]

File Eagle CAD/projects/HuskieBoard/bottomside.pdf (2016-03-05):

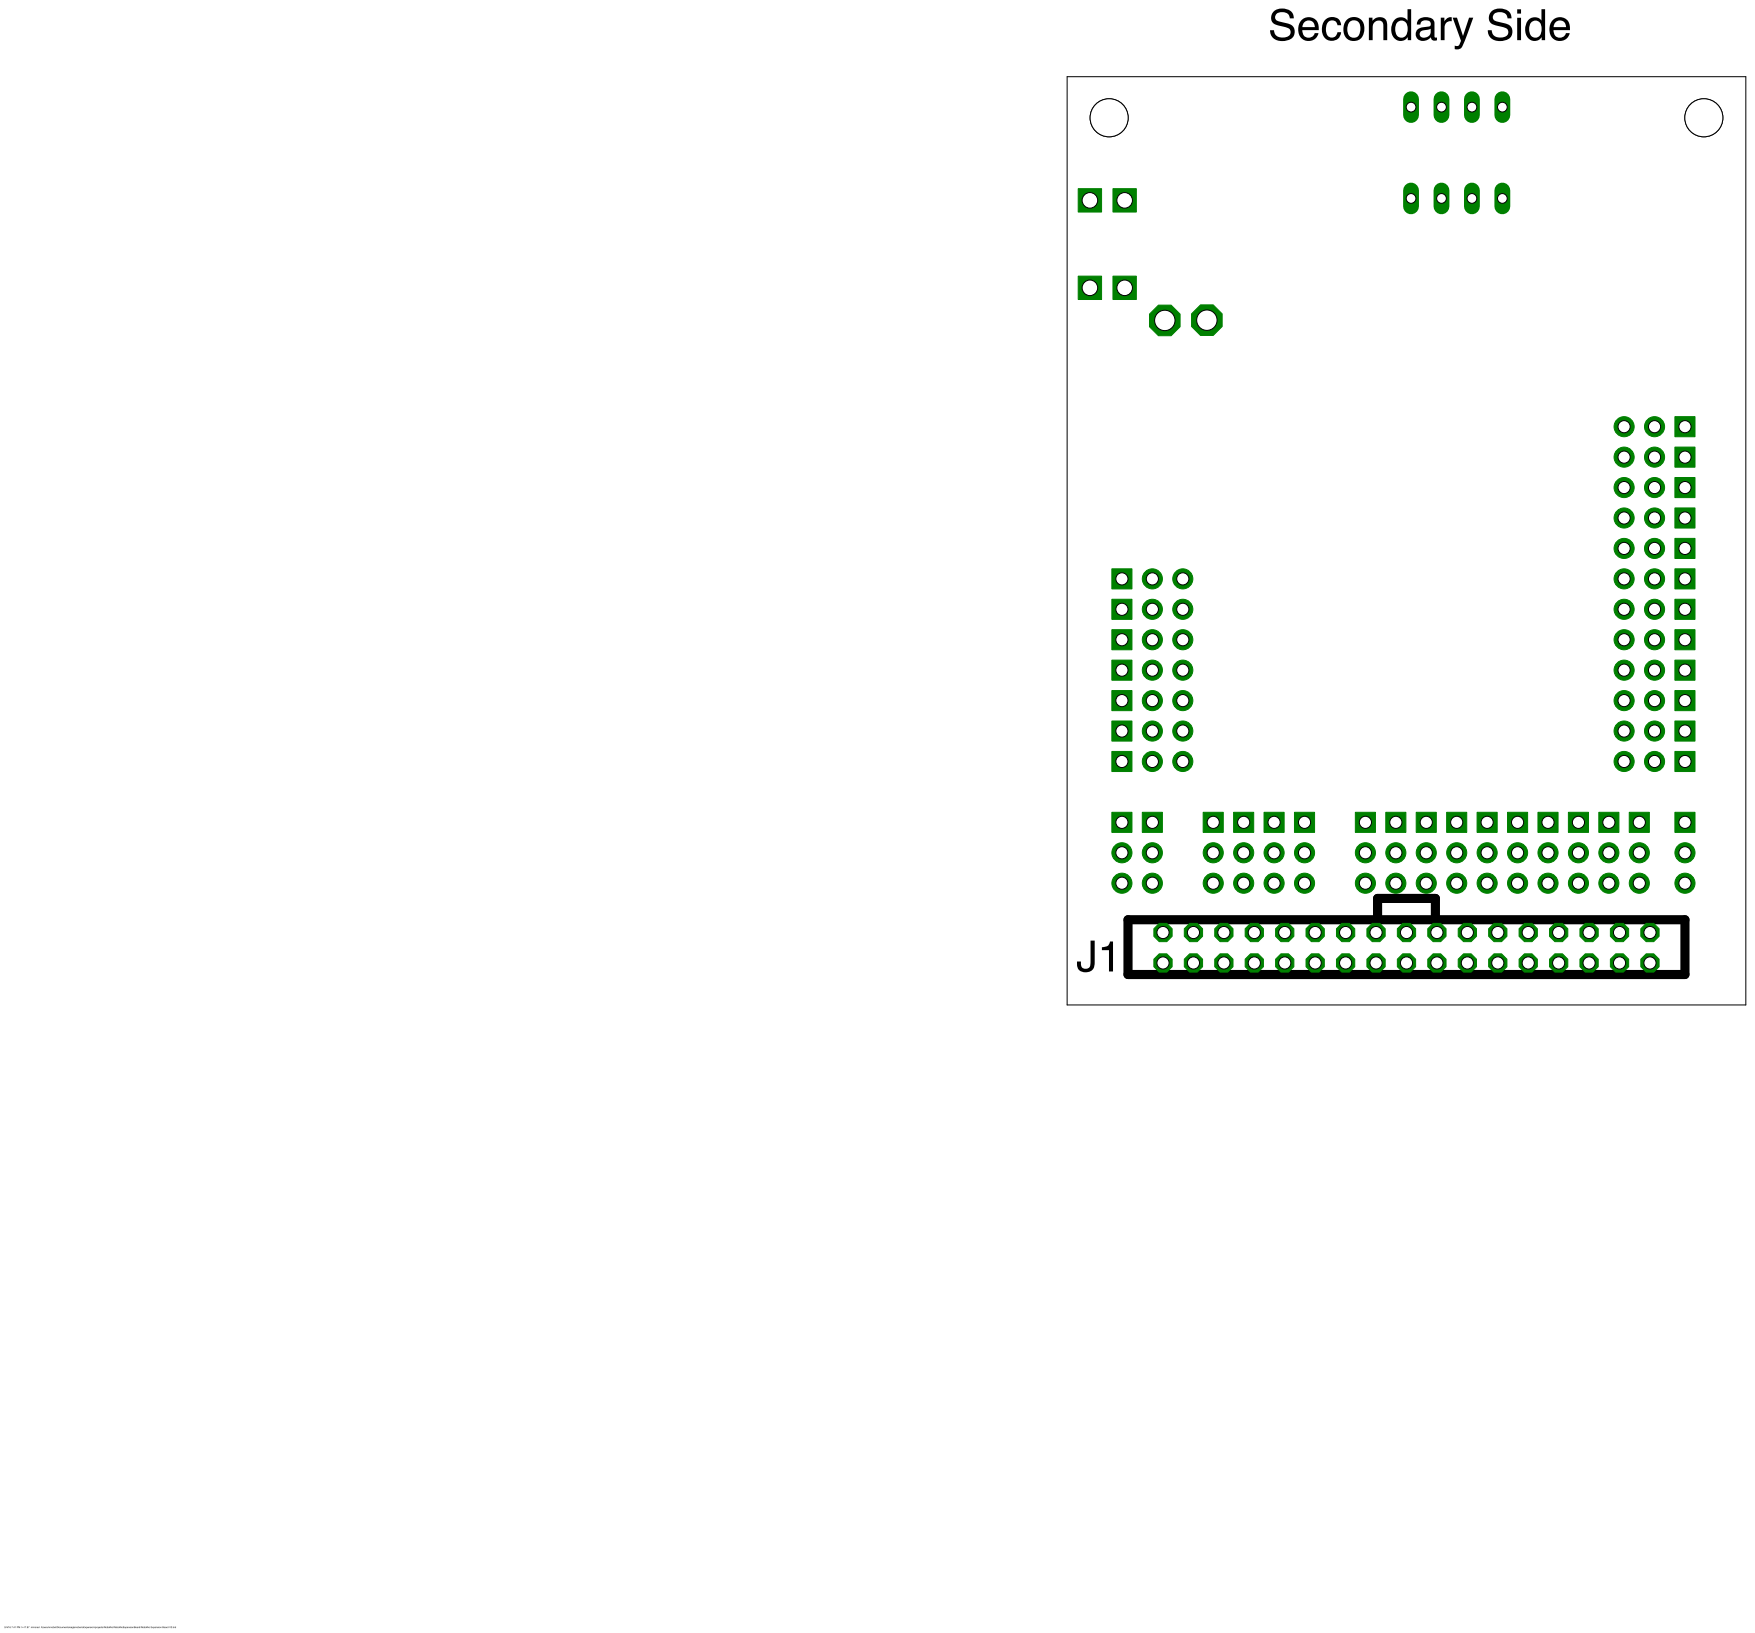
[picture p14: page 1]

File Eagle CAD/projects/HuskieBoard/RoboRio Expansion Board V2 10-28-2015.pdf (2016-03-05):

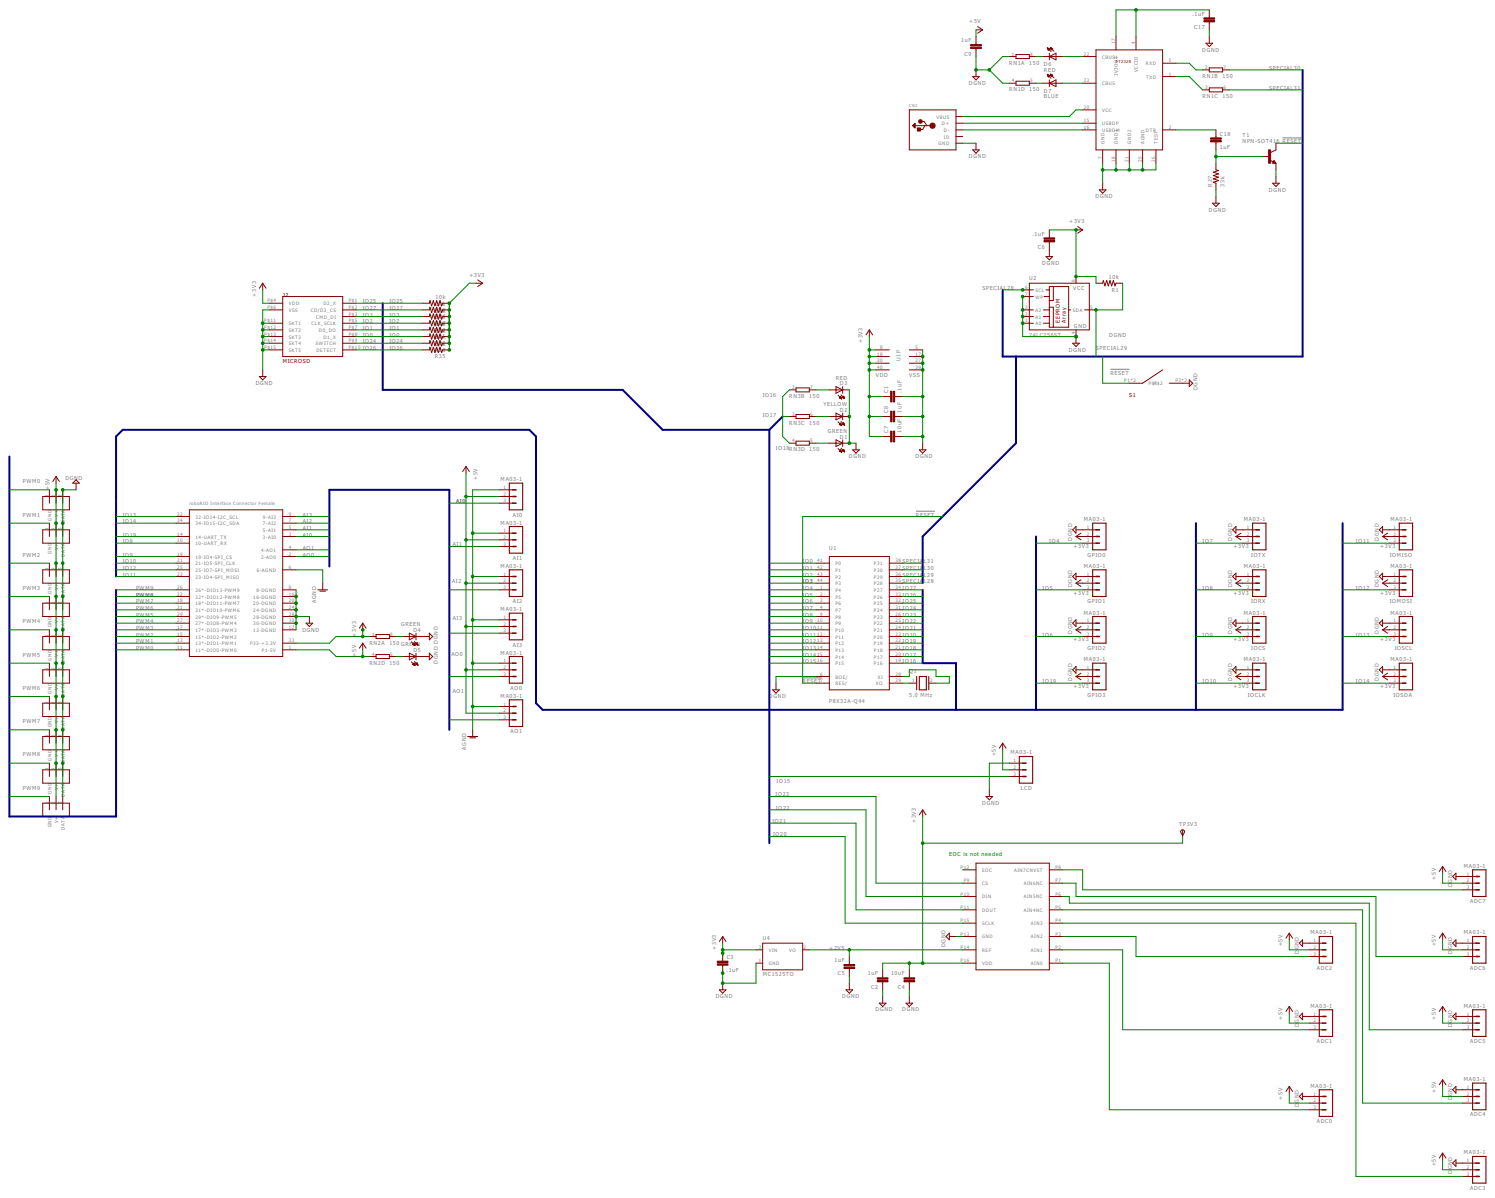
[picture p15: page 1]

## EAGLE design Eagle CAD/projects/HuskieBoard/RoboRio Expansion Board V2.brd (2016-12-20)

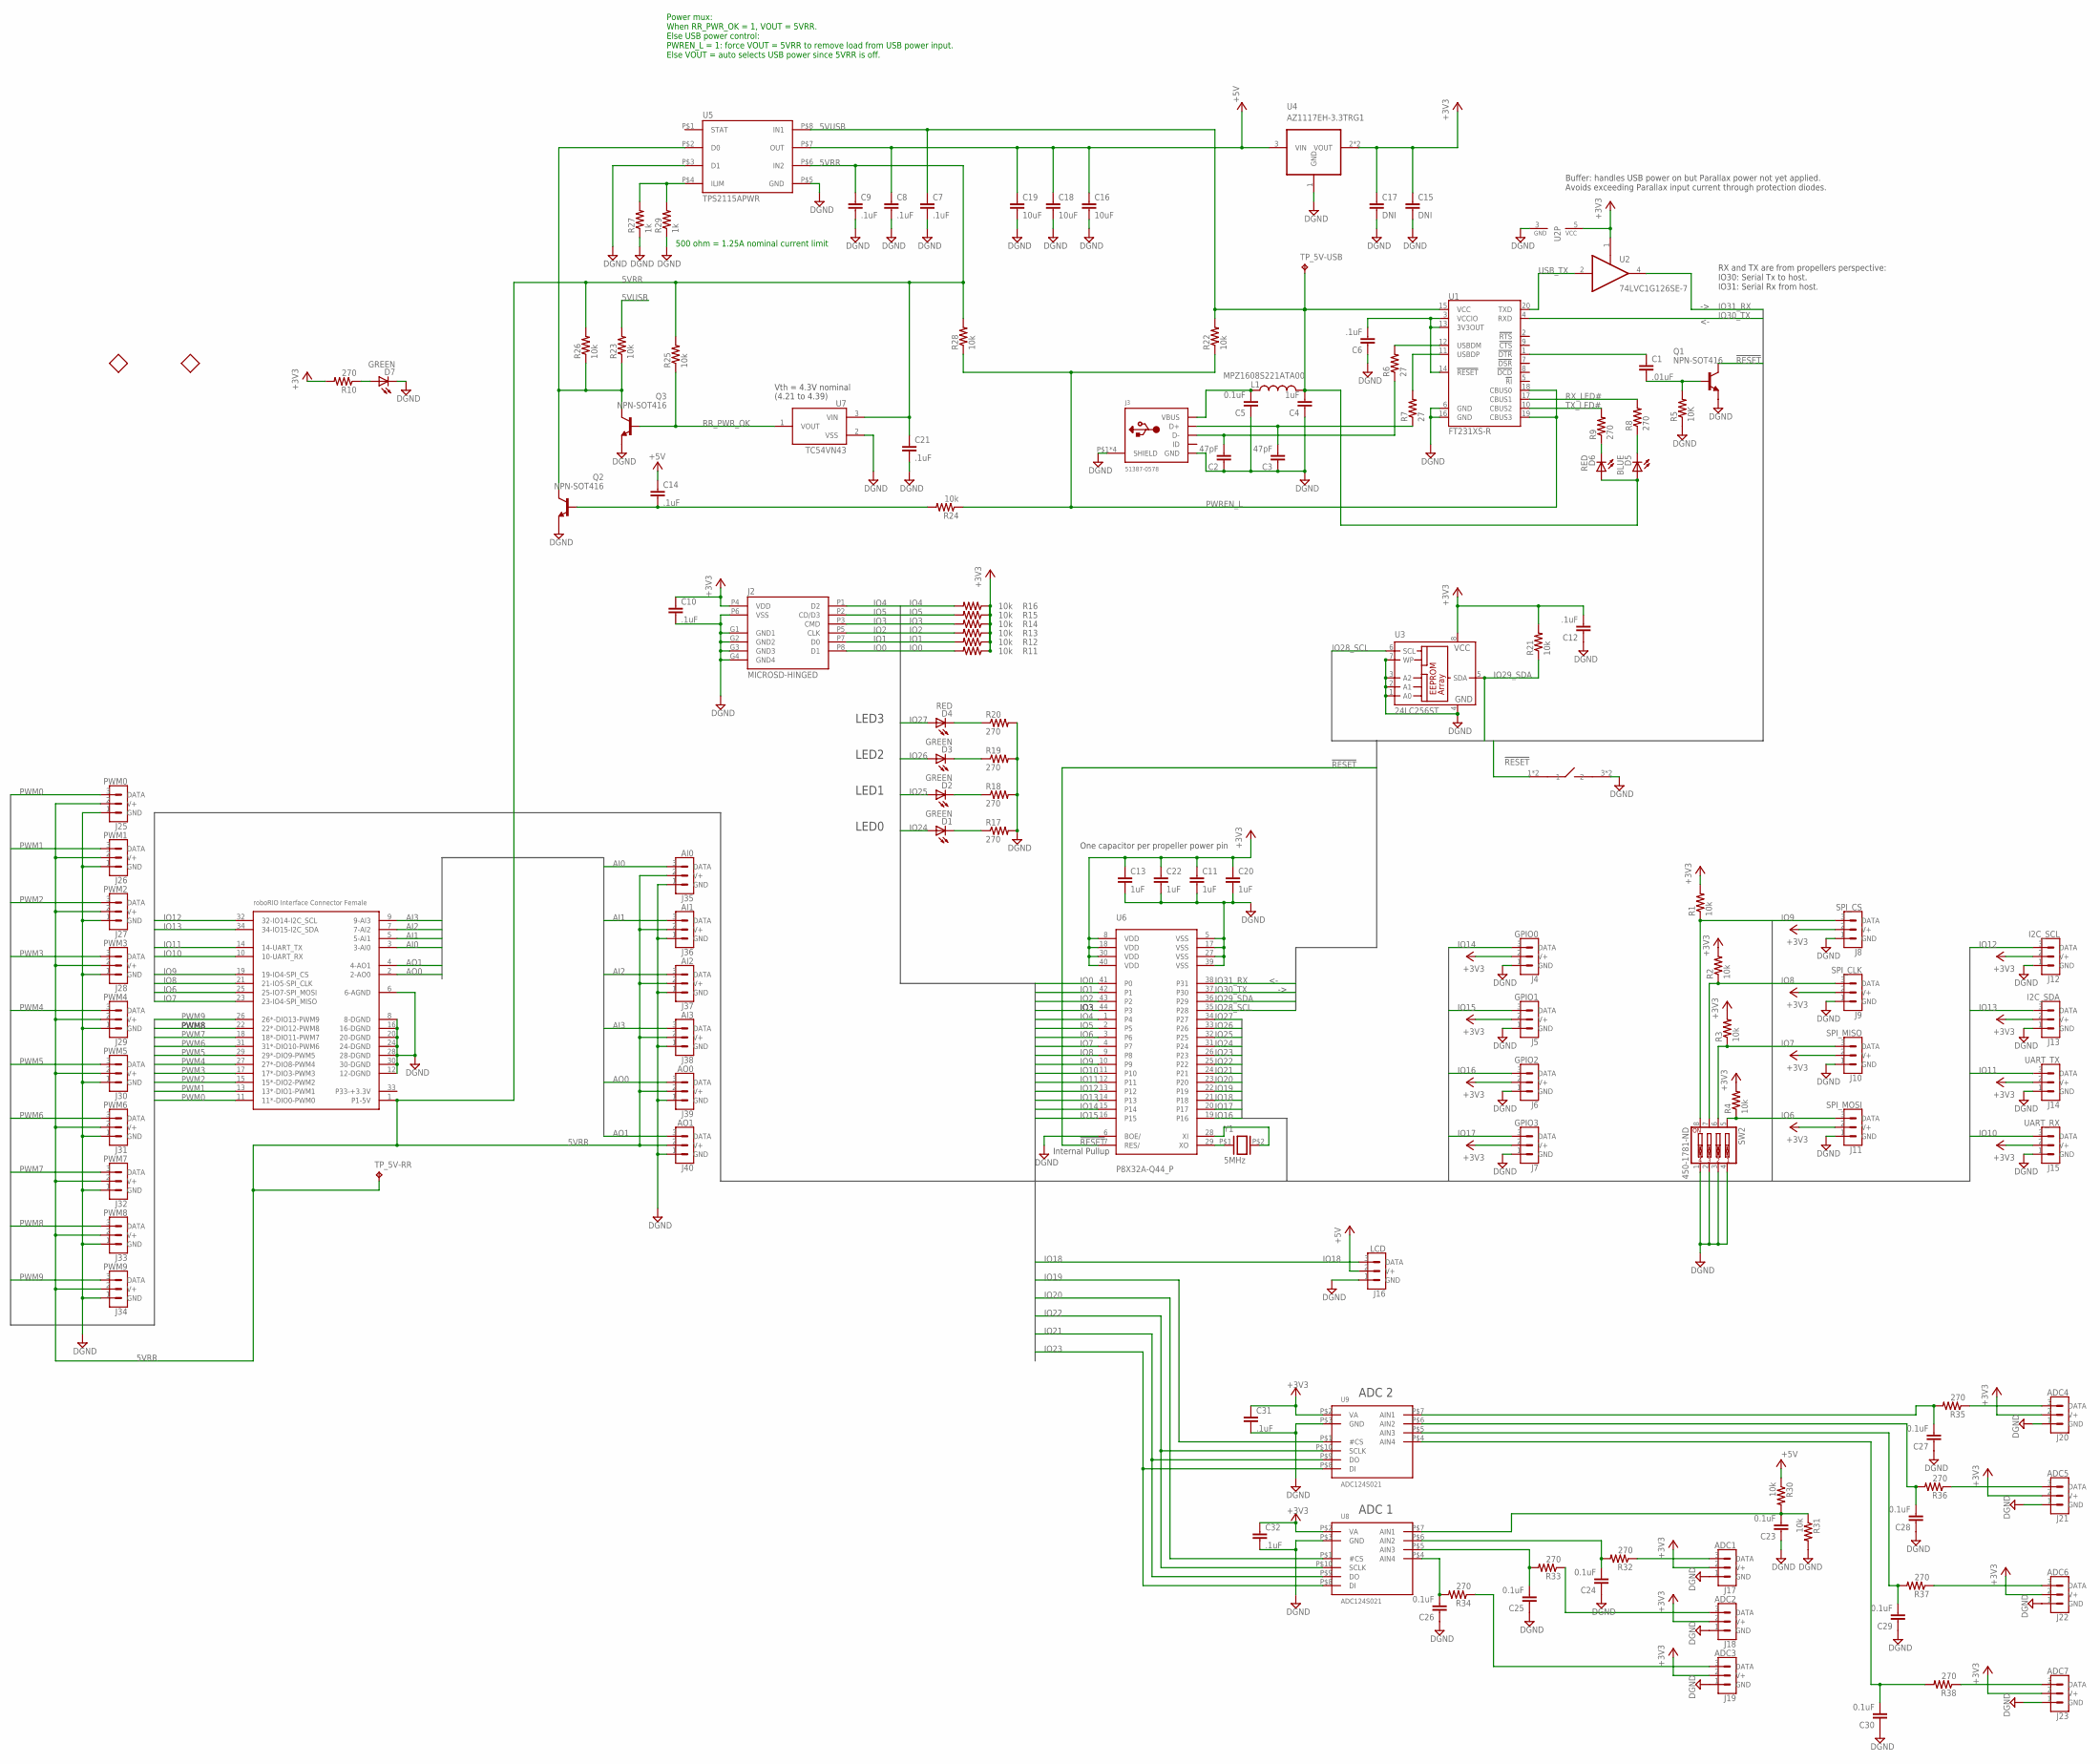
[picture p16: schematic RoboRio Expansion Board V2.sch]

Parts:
C1: .01uF; C0603K
C2, C3: 47pF; C0603K
C4, C11, C13, C20, C22: 1uF; C0603K
C5, C23, C24, C25, C26, C27, C28, C29, C30: 0.1uF; C0603K
C6, C7, C8, C9, C10, C12, C14, C21, C31, C32: .1uF; C0603K
C15, C17: DNI; C0805K
C16, C18, C19: 10uF; C0805K
D1, D2, D3, D7: GREEN; CHIPLED_0603
D4, D6: RED; CHIPLED_0603
D5: BLUE; CHIPLED_0603
J1: RRINTERFACE-FEMALE; RRINT-FEMALE
J2: MICROSD-HINGED; MICRO_SD_HINGED_TYPE
J3: 51387-0578; USB-MINIB-0513870578
J4: GPIO0; 3PINPACKAGE
J5: GPIO1; 3PINPACKAGE
J6: GPIO2; 3PINPACKAGE
J7: GPIO3; 3PINPACKAGE
J8: SPI_CS; 3PINPACKAGE
J9: SPI_CLK; 3PINPACKAGE
J10: SPI_MISO; 3PINPACKAGE
J11: SPI_MOSI; 3PINPACKAGE
J12: I2C_SCL; 3PINPACKAGE
J13: I2C_SDA; 3PINPACKAGE
J14: UART_TX; 3PINPACKAGE
J15: UART_RX; 3PINPACKAGE
J16: LCD; 3PINPACKAGE
J17: ADC1; 3PINPACKAGE
J18: ADC2; 3PINPACKAGE
J19: ADC3; 3PINPACKAGE
J20: ADC4; 3PINPACKAGE
J21: ADC5; 3PINPACKAGE
J22: ADC6; 3PINPACKAGE
J23: ADC7; 3PINPACKAGE
J25: PWM0; 3PINPACKAGE
J26: PWM1; 3PINPACKAGE
J27: PWM2; 3PINPACKAGE
J28: PWM3; 3PINPACKAGE
J29: PWM4; 3PINPACKAGE
J30: PWM5; 3PINPACKAGE
J31: PWM6; 3PINPACKAGE
J32: PWM7; 3PINPACKAGE
J33: PWM8; 3PINPACKAGE
J34: PWM9; 3PINPACKAGE
J35: AI0; 3PINPACKAGE
J36: AI1; 3PINPACKAGE
J37: AI2; 3PINPACKAGE
J38: AI3; 3PINPACKAGE
J39: AO0; 3PINPACKAGE
J40: AO1; 3PINPACKAGE
L1: MPZ1608S221ATA00; 0603
Q1, Q2, Q3: NPN-SOT416; SC75_INFINEON
R1, R2, R3, R4, R11, R12, R13, R14, R15, R16, R21, R22, R23, R24, R25, R26, R28, R30, R31: 10k; R0603
R5: 10K; R0603
R6, R7: 27; R0603
R8, R9, R10, R17, R18, R19, R20, R32, R33, R34, R35, R36, R37, R38: 270; R0603
R27, R29: 1k; R0603
SW1: RESETBUTTON9001DEFAULT; RESETBUTTON9001
SW2: 450-1781-ND; EDG-04
TP_5V-RR, TP_5V-USB: TPPAD1-17; P1-17
U1: FT231XS-R; SSOP20_L
U2: 74LVC1G126SE-7; SC70-5
U3: 24LC256ST; TSSOP8
U4: AZ1117EH-3.3TRG1; SOT223; MPN AZ1117EH-3.3TRG1
U5: TPS2115APWR; TSSOP-8
U6: P8X32A-Q44_P; P8X32A-Q44
U7: TC54VN43; SOT23
U8, U9: ADC124S021; ADC124S021VSSOP
U$1, U$2: FIDUCIAL_DIAMOND; FIDUCIAL_40MIL_DIAMOND
Y1: 5MHz; HC\49US

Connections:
5VRR: C9.1, C21.1, J1.1 (P1-5V), J25.2 (V+), J26.2 (V+), J27.2 (V+), J28.2 (V+), J29.2 (V+), J30.2 (V+), J31.2 (V+), J32.2 (V+), J33.2 (V+), J34.2 (V+), J35.2 (V+), J36.2 (V+), J37.2 (V+), J38.2 (V+), J39.2 (V+), J40.2 (V+), R25.2, R26.2, R28.2, TP_5V-RR.TP, U5.P$6 (IN2), U7.3 (VIN)
5VUSB: C4.2, C7.1, D5.A, D6.A, L1.2, R22.2, R23.2, TP_5V-USB.TP, U1.15 (VCC), U5.P$8 (IN1)
!RESET: Q1.3 (C), SW1.1, SW1.2 (1), U6.7 (RES/)
+3V3: C10.1, C11.1, C12.2, C13.1, C15.1, C17.1, C20.1, C22.1, C31.1, C32.1, J2.P4 (VDD), J4.2 (V+), J5.2 (V+), J6.2 (V+), J7.2 (V+), J8.2 (V+), J9.2 (V+), J10.2 (V+), J11.2 (V+), J12.2 (V+), J13.2 (V+), J14.2 (V+), J15.2 (V+), J17.2 (V+), J18.2 (V+), J19.2 (V+), J20.2 (V+), J21.2 (V+), J22.2 (V+), J23.2 (V+), R1.2, R2.2, R3.2, R4.2, R10.2, R11.1, R12.1, R13.1, R14.1, R15.1, R16.1, R21.2, U2.1 (OE), U2.5 (VCC), U3.8 (VCC), U4.2 (VOUT), U4.4 (VOUT), U6.8 (VDD), U6.18 (VDD), U6.30 (VDD), U6.40 (VDD), U8.P$2 (VA), U9.P$2 (VA)
+5V: C8.1, C14.1, C16.1, C18.1, C19.1, J16.2 (V+), R30.1, U4.3 (VIN), U5.P$7 (OUT)
AI0: J1.3 (3-AI0), J35.3 (DATA)
AI1: J1.5 (5-AI1), J36.3 (DATA)
AI2: J1.7 (7-AI2), J37.3 (DATA)
AI3: J1.9 (9-AI3), J38.3 (DATA)
AO0: J1.2 (2-AO0), J39.3 (DATA)
AO1: J1.4 (4-AO1), J40.3 (DATA)
DGND: C2.1, C3.1, C4.1, C5.1, C6.1, C7.2, C8.2, C9.2, C10.2, C11.2, C12.1, C13.2, C15.2, C16.2, C17.2, C18.2, C19.2, C20.2, C21.2, C22.2, C23.1, C24.1, C25.1, C26.1, C27.1, C28.1, C29.1, C30.1, C31.2, C32.2, D7.C, J1.6 (6-AGND), J1.8 (8-DGND), J1.12 (12-DGND), J1.16 (16-DGND), J1.20 (20-DGND), J1.24 (24-DGND), J1.28 (28-DGND), J1.30 (30-DGND), J2.G1 (GND1), J2.G2 (GND2), J2.G3 (GND3), J2.G4 (GND4), J2.P6 (VSS), J3.GND, J3.P$1 (SHIELD), J3.P$2 (SHIELD), J3.P$3 (SHIELD), J3.P$4 (SHIELD), J4.1 (GND), J5.1 (GND), J6.1 (GND), J7.1 (GND), J8.1 (GND), J9.1 (GND), J10.1 (GND), J11.1 (GND), J12.1 (GND), J13.1 (GND), J14.1 (GND), J15.1 (GND), J16.1 (GND), J17.1 (GND), J18.1 (GND), J19.1 (GND), J20.1 (GND), J21.1 (GND), J22.1 (GND), J23.1 (GND), J25.1 (GND), J26.1 (GND), J27.1 (GND), J28.1 (GND), J29.1 (GND), J30.1 (GND), J31.1 (GND), J32.1 (GND), J33.1 (GND), J34.1 (GND), J35.1 (GND), J36.1 (GND), J37.1 (GND), J38.1 (GND), J39.1 (GND), J40.1 (GND), Q1.2 (E), Q2.2 (E), Q3.2 (E), R5.1, R17.2, R18.2, R19.2, R20.2, R27.1, R29.1, R31.2, SW1.3 (2), SW1.4 (2), SW2.1, SW2.2, SW2.3, SW2.4, U1.6 (GND), U1.16 (GND), U2.3 (GND), U3.1 (A0), U3.2 (A1), U3.3 (A2), U3.4 (GND), U3.7 (WP), U4.1 (GND), U5.P$3 (D1), U5.P$5 (GND), U6.5 (VSS), U6.6 (BOE/), U6.17 (VSS), U6.27 (VSS), U6.39 (VSS), U7.2 (VSS), U8.P$3 (GND), U9.P$3 (GND)
IO0: J2.P8 (D1), R11.2, U6.41 (P0)
IO1: J2.P7 (D0), R12.2, U6.42 (P1)
IO2: J2.P5 (CLK), R13.2, U6.43 (P2)
IO3: J2.P3 (CMD), R14.2, U6.44 (P3)
IO4: J2.P1 (D2), R16.2, U6.1 (P4)
IO5: J2.P2 (CD/D3), R15.2, U6.2 (P5)
IO6: J1.25 (25-IO7-SPI_MOSI), J11.3 (DATA), R4.1, SW2.5, U6.3 (P6)
IO7: J1.23 (23-IO4-SPI_MISO), J10.3 (DATA), R3.1, SW2.6, U6.4 (P7)
IO8: J1.21 (21-IO5-SPI_CLK), J9.3 (DATA), R2.1, SW2.7, U6.9 (P8)
IO9: J1.19 (19-IO4-SPI_CS), J8.3 (DATA), R1.1, SW2.8, U6.10 (P9)
IO10: J1.10 (10-UART_RX), J15.3 (DATA), U6.11 (P10)
IO11: J1.14 (14-UART_TX), J14.3 (DATA), U6.12 (P11)
IO12: J1.32 (32-IO14-I2C_SCL), J12.3 (DATA), U6.13 (P12)
IO13: J1.34 (34-IO15-I2C_SDA), J13.3 (DATA), U6.14 (P13)
IO14: J4.3 (DATA), U6.15 (P14)
IO15: J5.3 (DATA), U6.16 (P15)
IO16: J6.3 (DATA), U6.19 (P16)
IO17: J7.3 (DATA), U6.20 (P17)
IO18: J16.3 (DATA), U6.21 (P18)
IO19: U6.22 (P19), U9.P$1 (#CS)
IO20: U6.23 (P20), U8.P$1 (#CS)
IO21: U6.24 (P21), U8.P$9 (DO), U9.P$9 (DO)
IO22: U6.25 (P22), U8.P$10 (SCLK), U9.P$10 (SCLK)
IO23: U6.26 (P23), U8.P$8 (DI), U9.P$8 (DI)
IO24: D1.A, U6.31 (P24)
IO25: D2.A, U6.32 (P25)
IO26: D3.A, U6.33 (P26)
IO27: D4.A, U6.34 (P27)
IO28_SCL: U3.6 (SCL), U6.35 (P28)
IO29_SDA: R21.1, U3.5 (SDA), U6.36 (P29)
IO30_TX: U1.4 (RXD), U6.37 (P30)
IO31_RX: U2.4 (O), U6.38 (P31)
unnamed: C3.2, J3.D+, R7.1
unnamed: C2.2, J3.D-, R6.1
unnamed: C6.2, U1.3 (VCCIO), U1.13 (3V3OUT), U1.14 (!RESET)
unnamed: D7.A, R10.1
unnamed: C14.2, Q2.1 (B), R24.2
unnamed: J19.3 (DATA), R34.1
unnamed: J18.3 (DATA), R33.1
unnamed: C30.2, R38.2, U9.P$4 (AIN4)
unnamed: R27.2, R29.2, U5.P$4 (ILIM)
unnamed: D4.C, R20.1
unnamed: D1.C, R17.1
unnamed: D2.C, R18.1
unnamed: C26.2, R34.2, U8.P$4 (AIN4)
unnamed: C24.2, R32.2, U8.P$6 (AIN2)
unnamed: D3.C, R19.1
unnamed: D6.C, R9.1
unnamed: C1.1, U1.1 (!DTR)
unnamed: Q2.3 (C), Q3.3 (C), R23.1, R26.1, U5.P$2 (D0)
unnamed: C25.2, R33.2, U8.P$5 (AIN3)
unnamed: J17.3 (DATA), R32.1
unnamed: D5.C, R8.1
unnamed: R6.2, U1.12 (USBDM)
unnamed: C23.2, R30.2, R31.1, U8.P$7 (AIN1)
unnamed: C1.2, Q1.1 (B), R5.2
unnamed: R7.2, U1.11 (USBDP)
unnamed: C5.2, J3.VBUS, L1.1
unnamed: C29.2, R37.2, U9.P$5 (AIN3)
unnamed: U6.29 (XO), Y1.P$1 (1)
unnamed: J23.3 (DATA), R38.1
unnamed: J22.3 (DATA), R37.1
unnamed: U6.28 (XI), Y1.P$2 (2)
unnamed: C28.2, R36.2, U9.P$6 (AIN2)
unnamed: J21.3 (DATA), R36.1
unnamed: C27.2, R35.2, U9.P$7 (AIN1)
unnamed: J20.3 (DATA), R35.1
PWM0: J1.11 (11*-DIO0-PWM0), J25.3 (DATA)
PWM1: J1.13 (13*-DIO1-PWM1), J26.3 (DATA)
PWM2: J1.15 (15*-DIO2-PWM2), J27.3 (DATA)
PWM3: J1.17 (17*-DIO3-PWM3), J28.3 (DATA)
PWM4: J1.27 (27*-DIO8-PWM4), J29.3 (DATA)
PWM5: J1.29 (29*-DIO9-PWM5), J30.3 (DATA)
PWM6: J1.31 (31*-DIO10-PWM6), J31.3 (DATA)
PWM7: J1.18 (18*-DIO11-PWM7), J32.3 (DATA)
PWM8: J1.22 (22*-DIO12-PWM8), J33.3 (DATA)
PWM9: J1.26 (26*-DIO13-PWM9), J34.3 (DATA)
PWREN_L: R22.1, R24.1, R28.1, U1.18 (CBUS0), U1.19 (CBUS3)
RR_PWR_OK: Q3.1 (B), R25.1, U7.1 (VOUT)
RX_LED#: R8.2, U1.17 (CBUS1)
TX_LED#: R9.2, U1.10 (CBUS2)
USB_TX: U1.20 (TXD), U2.2 (I)

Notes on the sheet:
500 ohm = 1.25A nominal current limit
Power mux: When RR_PWR_OK = 1, VOUT = 5VRR. Else USB power control: PWREN_L = 1: force VOUT = 5VRR to remove load from USB power input. Else VOUT = auto selects USB power since 5VRR is off.
RX and TX are from propellers perspective: IO30: Serial Tx to host. IO31: Serial Rx from host.
Internal Pullup
Vth = 4.3V nominal
(4.21 to 4.39)
ADC 1
ADC 2
LED0
LED1
LED2
LED3
One capacitor per propeller power pin
Buffer: handles USB power on but Parallax power not yet applied. Avoids exceeding Parallax input current through protection diodes.

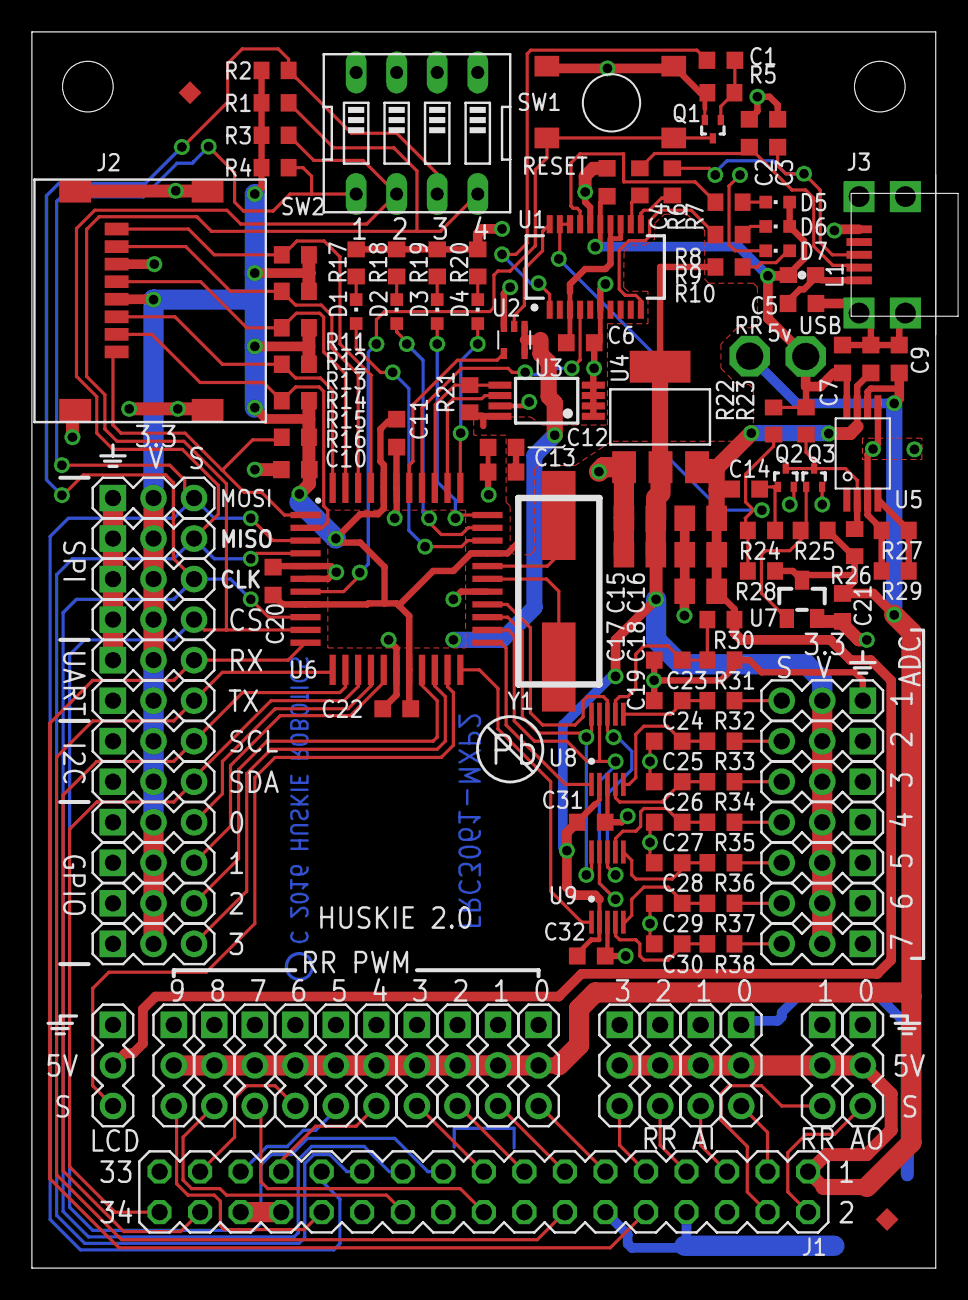
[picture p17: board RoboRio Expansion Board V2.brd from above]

Board: 2 copper layers, 56.6 x 77.5 mm, 137 parts (0 on the bottom side), 94 nets.

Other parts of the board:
DRILEGEND: DRILEGEND

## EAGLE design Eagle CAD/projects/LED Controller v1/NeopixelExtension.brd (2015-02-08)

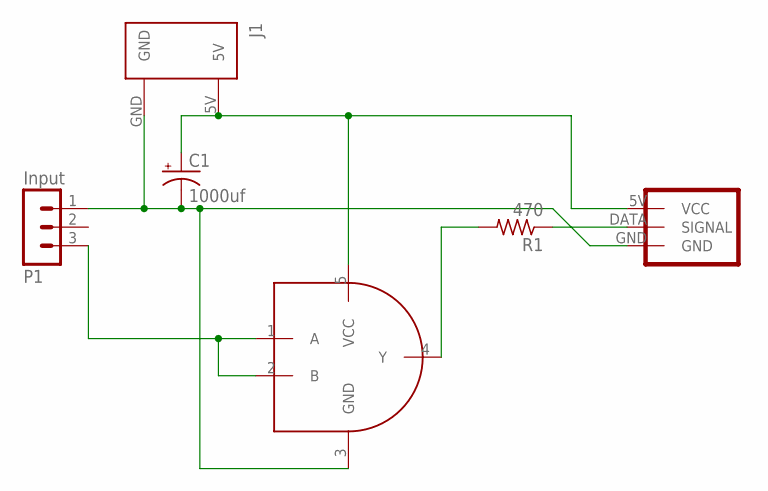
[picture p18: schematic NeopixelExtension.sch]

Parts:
C1: 1000uf; E5-10,5
J1: POWER
P1: Input; MA03-1
R1: 470; R1206
U1: 74AHCT1G08; SOT25
U$2: NEOPIXEL1; NEODIRECTSOLDERORMA03-1

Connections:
GND: C1.-, J1.GND, P1.1, U1.3 (GND), U$2.GND
unnamed: R1.1, U$2.DATA (SIGNAL)
unnamed: P1.3, U1.1 (A), U1.2 (B)
unnamed: R1.2, U1.4 (Y)
VCC: C1.+, J1.5V, U1.5 (VCC), U$2.5V (VCC)

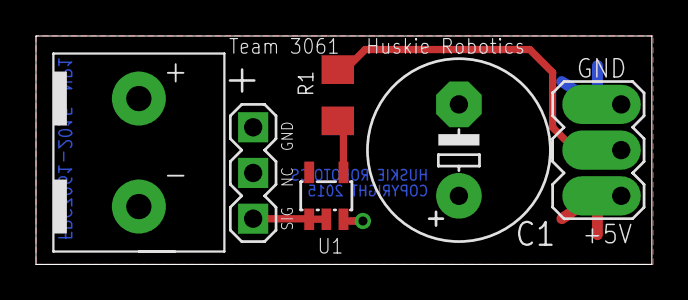
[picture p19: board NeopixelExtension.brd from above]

Board: 2 copper layers, 34.2 x 12.7 mm, 6 parts (0 on the bottom side), 5 nets.

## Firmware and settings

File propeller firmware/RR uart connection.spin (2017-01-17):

{AUTHOR: Lucas Rezac, Calvin Field}                                                                                                                       
{TITLE: LOG STRING}                                                                                                                           
{REVISED BY: Brandon John, Lucas Rezac, Calvin Field}                                                                                                     
CON     'Permanent constants
                                                                                                                                    
        _clkmode = xtal1 + pll16x                                               'Standard clock mode * crystal frequency = 80 MHz           
        _xinfreq = 5_000_000                                                                                                              
                                                                                                                                            
        
        lcd_pin     = 18        'LCD communication pin
        
        prop_rx     = 31        'Prop-Plug communication recieve pin
        prop_tx     = 30        'Prop-Plug communication transmit pin
        
        eeprom_sda  = 29        'EEPROM data line
        eeprom_scl  = 28        'EEPROM clock line
       
        adc_CS1     = 20        
        adc_CS2     = 19        
        adc_DO      = 21        
        adc_DI      = 23       
        adc_CLK     = 22       
        
        gpio_0      = 14        'General Purpose Input Output Pin 0
        gpio_1      = 15        'General Purpose Input Output Pin 1
        gpio_2      = 16        'General Purpose Input Output Pin 2
        gpio_3      = 17        'General Purpose Input Output Pin 3

        robo_i2c_scl =12
        robo_i2c_sda =13
        
        robo_tx     = 10        'RoboRIO Transmit Pin
        robo_rx     = 11        'RoboRIO Recieve Pin
                                
        robo_mosi   = 6         'RoboRIO MOSI   
        robo_miso   = 7         'RoboRIO MISO   
        robo_clk    = 8         'RoboRIO Clock Pin 
        robo_cs     = 9         'RoboRIO CS Pin    

        switch_1    = robo_mosi      '6
        switch_2    = robo_miso      '7
        switch_3    = robo_clk       '8
        switch_4    = robo_cs        '9
        
        robo_sda    = 13        'RoboRIO SDA
        robo_scl    = 12        'RoboRIO SCL
        
        sd_d0       = 1         'SD Card DO
        sd_d1       = 0         'SD Card Data 1
        sd_d2       = 4         'SD Card Data 2      
        sd_d3       = 5         'SD Card CS
        sd_cmd      = 3         'SD Card CMD
        sd_clk      = 2         'SD Card Clock pin
                           
        sd_SPI_DO   = sd_d0
        sd_SPI_CLK  = sd_clk
        sd_SPI_DI   = sd_cmd
        sd_SPI_CS   = sd_d3
        
        led_0       = 24        'Onboard Green  LED 0
        led_1       = 25        'Onboard Green  LED 1
        led_2       = 26        'Onboard Green  LED 2
        led_3       = 27        'Onboard Red    LED 3

        
        ' Prevent GPIO output control on certain pins
        ' When the serial API sets DIRA or OUTA, first AND the request
        ' with this constant so that it cannot break communication.
        OUTPUT_MASK = %00_00_1111_00000_1111111_00_1111_000000
        '          EEPROM+Ser      ADC         UART     SDCARD
        'This allows control of the 4 LEDs, GPIO, roboRIO rx and tx
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

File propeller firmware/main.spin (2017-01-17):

con
        _clkmode    = xtal1 + pll16x                                           'Standard clock mode * crystal frequency = 80 MHz
        _xinfreq    = 5_000_000
        
        lcd_pin     = 18        'LCD communication pin
        lcd_baud    = 19_200    'LCD communication baudrate
        LCD_SIZE    = 4         'default lcd size is 4 lines
        
        prop_rx     = 31        'Prop-Plug communication recieve pin
        prop_tx     = 30        'Prop-Plug communication transmit pin
        
        eeprom_sda  = 29        'EEPROM data line  -- Transfers data based on clock line
        eeprom_scl  = 28        'EEPROM clock line -- Keeps time to ensure packet viability
       
        adc_CS1     = 20        
        adc_CS2     = 19        
        adc_DO      = 21        
        adc_DI      = 23       
        adc_CLK     = 22       
        
        gpio_0      = 14        'General Purpose Input Output Pin 0
        gpio_1      = 15        'General Purpose Input Output Pin 1
        gpio_2      = 16        'General Purpose Input Output Pin 2
        gpio_3      = 17        'General Purpose Input Output Pin 3

        robo_i2c_scl =12
        robo_i2c_sda =13
        
        robo_tx     = 11        'RoboRIO Transmit Pin
        robo_rx     = 10        'RoboRIO Recieve Pin
        
        robo_mosi   = 6         'RoboRIO MOSI   
        robo_miso   = 7         'RoboRIO MISO   
        robo_clk    = 8         'RoboRIO Clock Pin 
        robo_cs     = 9         'RoboRIO CS Pin    

        switch_1    = robo_mosi      '6
        switch_2    = robo_miso      '7
        switch_3    = robo_clk       '8
        switch_4    = robo_cs        '9
        
        robo_sda    = 13        'RoboRIO SDA
        robo_scl    = 12        'RoboRIO SCL
        
        sd_d0       = 1         'SD Card DO
        sd_d1       = 0         'SD Card Data 1
        sd_d2       = 4         'SD Card Data 2      
        sd_d3       = 5         'SD Card CS
        sd_cmd      = 3         'SD Card CMD
        sd_clk      = 2         'SD Card Clock pin
                           
        sd_SPI_DO   = sd_d0
        sd_SPI_CLK  = sd_clk
        sd_SPI_DI   = sd_cmd
        sd_SPI_CS   = sd_d3
        
        led_1       = 24        'Onboard Green  LED 1
        led_2       = 25        'Onboard Green  LED 2
        led_3       = 26        'Onboard Green  LED 3
        led_4       = 27        'Onboard Red    LED 4
        
        neopixel    = gpio_0    'Point Neopixel to GPIO Pin 0 -- For ease of use


        ROBORIO_UART_CONNECTION_BAUD = 230400    
                                
        FIRMWARE_MAJOR = 1 'up to 256
        FIRMWARE_MINOR = 4 'up to 256
        FIRMWARE_FIX   = 2 'up to 256
        FIRMWARE_TEST  = 0 'up to 256

        FIRMWARE_V = (FIRMWARE_MAJOR * |<0) + (FIRMWARE_MINOR * |<8) + (FIRMWARE_FIX* |<16) + (FIRMWARE_TEST *|<24) 

obj
        uart    : "RR uart connection"

pub main
    scroll
    {UART CONNECTION DRIVER}
    uart.init(ROBORIO_UART_CONNECTION_BAUD, FIRMWARE_V)
     
     
    'LED stuff, for autonomous mode selection
    DIRA[led_1 .. led_4] := $F
    repeat 
      OUTA[led_1 .. led_4] := !INA[robo_MOSI .. robo_CS]

pri scroll 'Quickly scroll through the LEDs twice, to clearly show that the board just booted.
    OUTA[led_1 .. led_4] := 0
    DIRA[led_1 .. led_4] := $F
    repeat 2                       
      waitcnt(cnt+clkfreq/10)
      OUTA[led_1 .. led_4] := %0001
      waitcnt(cnt+clkfreq/10)
      OUTA[led_1 .. led_4] := %0011
      waitcnt(cnt+clkfreq/10)
      OUTA[led_1 .. led_4] := %0010
      waitcnt(cnt+clkfreq/10)
      OUTA[led_1 .. led_4] := %0110
      waitcnt(cnt+clkfreq/10)
      OUTA[led_1 .. led_4] := %0100
      waitcnt(cnt+clkfreq/10)
      OUTA[led_1 .. led_4] := %1100
      waitcnt(cnt+clkfreq/10)
      OUTA[led_1 .. led_4] := %1000
      waitcnt(cnt+clkfreq/10)
      OUTA[led_1 .. led_4] := %1001
    OUTA[led_1 .. led_4] := 0
    DIRA[led_1 .. led_4] := 0                        

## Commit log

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2014-11-21 Added libraries, added demo file
    These libraries hold the parts that were not included automatically,
    only missing the RR interface,5v reg, other 5v reg, .1 inch standoffs,
    and the MAX11639EEE.
    We may need to find a different ADC, preferably a through hole chip.
    The new partsFound schematic holds one of each part, except those
    mentioned to be missing.
    The Parts Spread Sheet on google drive has a column(F) that names the
    Eagle part number so the schematic may not be needed.
    [partsFound.sch]
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2014-12-10 Revert "to be reverted"
    This reverts commit 2973be1ba1c10ff95a64a450bc3c262aefbf1471.
    [3518-eagle.sch, 3518.sch, Arduino_MEGA2560_ref.brd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]
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2014-12-24 Removed Gyro
    Since we can't solder it, We won't need it on the board. It may? be
    replaced by a connector to an external gyro.
    [ExpansionBoardV1.brd, ExpansionBoardV1.sch]
2014-12-24 Added ADC
    Still needs to be connected and have it's pins broken out.
    [ExpansionBoardV1.brd, ExpansionBoardV1.sch]
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2015-01-08 removed board file
    since it was causing a file diff error
    [ExpansionBoardV1.brd]
2015-01-08 Updated resistor to the correct package
    The I2C pullup for the eeprom
    How can we only have one resistor?
    [ExpansionBoardV1.sch]
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2015-01-08 Made Everything better with LEDS
    Fixes
    [ExpansionBoardV1.sch]
2015-01-08 Revert "Revised power supplys to ADC inputs"
    This reverts commit 721caa68c9f3b3a09d4c967e259fd2a38c3a9dbd.
    [ExpansionBoardV1.sch]
2015-01-08 Revert "Made Everything better with LEDS"
    This reverts commit cd97a4d0e598ad7885acf7d4475d7f4afa4810bb.
    [ExpansionBoardV1.sch]
2015-01-08 Reverting to 0bfd424 to fix our git issues.
    [ExpansionBoardV1.sch]
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2015-01-08 Fixed LED polarities, ADC power supplies
    [ExpansionBoardV1.sch]
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2015-01-08 Fixed Eric's io pin connections
    and added propeller to the board layout
    [ExpansionBoardV1.brd, ExpansionBoardV1.sch]
2015-01-08 Fixed io 28..31
    They were not connected for some reason
    [ExpansionBoardV1.brd, ExpansionBoardV1.sch]
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2015-01-08 Replaced all 3 pin connectors with the new version
    using find/replace. Also attached all ot the ADC input pins
    [ExpansionBoardV1.brd, ExpansionBoardV1.sch]
2015-01-08 Fixed many ERC errors
    [ExpansionBoardV1.sch]
2015-01-08 found correct package for LEDs
    [ExpansionBoardV1.brd, ExpansionBoardV1.sch]
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2015-01-10 AIO has been broken out
    -Eric
    [ExpansionBoardV1.brd, ExpansionBoardV1.sch]
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2015-01-13 Updated ADC
    need to correct which pins it is connected to;
    need to add resistors to part list;
    need to describe new usage of the ADC;
    [ExpansionBoardV1.brd, ExpansionBoardV1.sch]
2015-01-13 Updated ADC(actually)
    Why doesn’t Eagle auto-save? :(
    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
    [ExpansionBoardV1.brd, ExpansionBoardV1.sch]
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2015-01-19 Updated ADC setup to connect to power
    also fixed RS button icon
    [ExpansionBoardV1.brd, ExpansionBoardV1.sch]
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2015-01-21 Revert "Added Lowpass filter to the ADC's 3 pin inputs"
    This reverts commit 7b3298678fa882268127de68b568754e7b61ca6d.
    [ExpansionBoardV1.sch]
2015-01-21 Added lowpass filters to adc inputs
    (Without reverting Mr Emge’s work this time)
    [ExpansionBoardV1.sch, partsFound.sch]
2015-01-22 ADC Filter added ... Correctly this time
    Will delete he RRio extension quite soon
    [ExpansionBoardV1.sch]
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2015-01-25 Updated Expansion board with various small issues
    removed the neopixel circuit from the main board
    [ExpansionBoardV1.sch]
2015-01-25 Almost finished neopixel board design
    Still has slight issues with the DRC, a couple of traces go to close to
    edge of board.
    [NeopixelExtension.brd, NeopixelExtension.sch]
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2015-01-27 Fixed SD card hotspot
    Dubstep is very good music.
    [ExpansionBoardV1.sch]
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2015-01-31 Replace SD card with micro SD
    [ExpansionBoardV1.brd, ExpansionBoardV1.sch]
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2015-02-02 Updated neopixel brd file with team name/number
    also fixed a few small routing errors. I believe it is finished now.
    [NeopixelExtension.brd]
2015-02-02 Fixed MANY grid issues
    trying to have the parts at 100mil, or at least 10mil spacings. Also
    loaded design rules into the expansion board, and added the dgnd plane
    [ExpansionBoardV1.brd, NeopixelExtension.brd]
2015-02-02 Updated lots of routing, fixed DRC errors
    Adjusted a few pins to the SD card for easier/better routing
    [ExpansionBoardV1.brd, ExpansionBoardV1.sch]
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2015-02-03 Fixed some small airwire issues
    6 to go
    [ExpansionBoardV1.brd]
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2015-02-04 Checked all the packages changed some small errors
    [ExpansionBoardV1.brd]
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2015-02-04 Fixed some hole spacing issues
    and their wires to them.
    [ExpansionBoardV1.brd]
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2015-02-04 Updated silkscreen markings, names of parts
    and fixed small issue in microSD card
    [ExpansionBoardV1.brd, ExpansionBoardV1.sch]
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2015-02-05 Fixed most silkscreen errors
    ADC inputs still need help.
    [ExpansionBoardV1.brd]
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2015-02-05 Fixed wires
    in preparation for labels
    [ExpansionBoardV1.brd]
2015-02-05 Revert "Fixed most silkscreen errors"
    This reverts commit 515101619b3595e4de045d44e07f2dfb83f59f1f.
    [ExpansionBoardV1.brd]
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2015-02-06 Back annotation, fix DRC trace separation
    Still has some DRC errors but I'm not sure how to fix them.
    Also can't see S1 on the schematic.
    [ExpansionBoardV1.brd, ExpansionBoardV1.sch]
2015-02-06 Fixed all important DRC errors
    By important, the only ones that are left are stop mask with tPlace,
    since those will be removed by the Fab house, or we will remove with a
    gerber editor, but won't be worth doing now.
    [ExpansionBoardV1.brd, ExpansionBoardV1.sch]
2015-02-06 Fixed ResetButton lbr, updated DRU we are using
    It is now defaultTemp.dru
    [ExpansionBoardV1.brd, ExpansionBoardV1.sch]
2015-02-07 SD Card keepout, silk
    Rerouted conflicts from missing SD card keepout. Modified silk text.
    Modified 3-pin connector silk.
    [ExpansionBoardV1.brd, ExpansionBoardV1.sch]
2015-02-07 Clean up
    Silk updates, Spread out tight routing on prop pins 5-8 and 13-20.
    [ExpansionBoardV1.brd, ExpansionBoardV1.sch]
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2015-02-07 Revert "Changed drill on resistor pack for sd card to .8"
    This reverts commit b5448f1bc8ea66a9491760b76c11c9b0a55611b1.
    [ExpansionBoardV1.brd]
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2015-02-08 Updated copyright signs to not use © symbol
    since that symbol doesn't work with vector fonts.
    Also regenerated all gerber files.
    Put all gerbers into 2 zips to send to MPCS
    We are done with the board!!!!
    (I hope)
    [ExpansionBoardV1.brd, NeopixelExtension.brd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]
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2015-02-21 Added MXP pin constants, updated file names
    Also many various fixes for using the new MXP board instead of the
    breadboard.
    [RR uart connection.spin]
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2015-03-21 small updates
    mostly quick fixes to comments
    double fileName buffer size
    [RR uart connection.spin]
2015-03-21 added time set capabilities
    SD Card logging still doesn't work, though.
    [RR uart connection.spin]
2015-03-22 Fixed date set command
    Hadn't been calculating checksum properly AND was updating the date
    AFTER file creation, which is the only time FSRW reads the date.
    [RR uart connection.spin]
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2015-03-27 Revert abb52cb..222644b
    This rolls back to commit abb52cb056ee1b827a0acc8afb0a04278cf39098.
    [ExpansionBoardV1.brd, RoboRio Expansion Board V2.brd, RoboRio Expansion Board V2.sch]
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2015-04-01 Revert "Merge remote-tracking branch 'origin/RoboRio-ExpansionBoard-V2' into RoboRio-ExpansionBoard-V2"
    This reverts commit b774243b9c15def8faa071487e762db8c276e9fe, reversing
    changes made to 810344a27810445190cf1cea2e5b732c8c738a36.
    [RoboRio Expansion Board V2.brd, RoboRio Expansion Board V2.sch]
2015-04-01 Revert f326de5..4e870d2
    This rolls back to commit f326de56033fa9d93aeca5845a304bb89d0f4444.
    [ExpansionBoardV1.brd, RoboRio Expansion Board V2.brd, RoboRio Expansion Board V2.sch]
2015-04-01 Revert 810344a..1659212
    This rolls back to commit 810344a27810445190cf1cea2e5b732c8c738a36.
    [ExpansionBoardV1.brd, RoboRio Expansion Board V2.brd, RoboRio Expansion Board V2.sch]
2015-04-01 Revert "Revert 810344a..1659212"
    This reverts commit b3dd55649a877628750982694ddcf49230273aee.
    [ExpansionBoardV1.brd, RoboRio Expansion Board V2.brd, RoboRio Expansion Board V2.sch]
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2015-07-20 Changed all resistors to surface mount(skipped ADC)
    Electronics fun fact: most prevalent resistor packages are pre built
    into Eagle, so there is no need to make them.
    [RoboRio Expansion Board V2.brd, RoboRio Expansion Board V2.sch]
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2015-07-21 Made super sketchy replacement for 10k sd resistor
    The first was a pin not SMT package. used our normal resistors instead,
    assuming space will not be an issue with the current packages,
    [RoboRio Expansion Board V2.brd, RoboRio Expansion Board V2.sch]
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2015-08-03 Removed the bad mini-usb part
    Removed because the library wasn't finished and was causing other issues
    for me.
    By not finished, it was a bunch of SMD pads laying all over the screen,
    with no logic to where they were placed. I suspect someone was
    frustrated :)
    [RoboRio Expansion Board V2.brd, RoboRio Expansion Board V2.sch]
2015-08-03 Fixed a few small schematic layout issues
    also removed old dip propeller, for some reason it hadn't been removed
    after it's replacement was added.
    [RoboRio Expansion Board V2.brd, RoboRio Expansion Board V2.sch]
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2015-09-02 sort of changed FT232 connections
    Remember to check the proper FT232 voltage, and USB B Mini voltage.
    Also, check for correct FT to USB connections.
    [RoboRio Expansion Board V2.brd, RoboRio Expansion Board V2.sch]
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2015-09-15 fixed connections to mini usb B
    remember to check this schematic drawing:
    http://forums.parallax.com/uploads/attachments/40745/103973.png
    [RoboRio Expansion Board V2.brd, RoboRio Expansion Board V2.sch]
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2015-10-14 Fixed 5v source to FT232R
    [RoboRio Expansion Board V2.sch]
2015-10-14 Fixed FT232R pins, added 5v-GND bypass capacitor
    [RoboRio Expansion Board V2.brd, RoboRio Expansion Board V2.sch]
2015-10-14 Fixed LED indicator LEDs
    [RoboRio Expansion Board V2.brd, RoboRio Expansion Board V2.sch]
2015-10-17 Added keepout, restrict layers to RoboRIO connector
    Also fixed a hole location
    updated library to show in layout
    Set tentative board dimensions
    [RoboRio Expansion Board V2.brd, RoboRio Expansion Board V2.sch]
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2015-10-25 Updated LED values to their color
    regenerated BOM with a few device name fixes
    [BOM v1.csv, BOM v2.csv, RoboRio Expansion Board V2.brd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]
2015-10-25 Fixed PropPlug library symbol
    Updated schematic with new symbol
    [RoboRio Expansion Board V2.sch]
2015-10-25 Fixed bom to true CSV.
    Why does Eagle use semicolons to separate values in a
    comma-separated-values file?
    Ugh.
    [BOM v2.csv]
2015-10-25 Fixed GND connections for USB converter
    [RoboRio Expansion Board V2.brd, RoboRio Expansion Board V2.sch]
2015-10-25 Fixed EEPROM package
    It now has a technology value of LC128, but we want to use the 24LC256ST
    chip! They have the same connections, so everything is ok.
    [RoboRio Expansion Board V2.brd, RoboRio Expansion Board V2.sch]
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2015-10-25 Fixed C4, C7 capacitor sizes
    [RoboRio Expansion Board V2.sch]
2015-10-25 Cleared up some ERC errors
    [RoboRio Expansion Board V2.sch]
2015-10-25 Added labels to reset line
    [RoboRio Expansion Board V2.sch]
2015-10-25 all ADC stuff is now on a common GND
    Also fixed the LCD's connection being offset by .05
    [RoboRio Expansion Board V2.sch]
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2015-10-27 Removed Prop Plug connector
    Since we now have USB, it isn't needed.
    Also fixed a straggling Analog GND issue.
    [RoboRio Expansion Board V2.sch]
2015-10-27 Small changes
    Made more space by moving stuff around
    USB 5V is no longer directly tied to RR 5V
    Removed fuses
    [RoboRio Expansion Board V2.sch]
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2015-11-01 Added a single 3.3v regulator
    We probably won't use this one, but it is very easy to remove
    [RoboRio Expansion Board V2.sch]
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2015-11-06 Added transistor for U6
    As it is, it WILL NOT WORK
    I am going through stuff on physical paper, and will update here when I
    can.
    [RoboRio Expansion Board V2.sch]
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2015-11-07 Revert "3 pin correction."
    This reverts commit bd97120c2b67397c0d11c617bf9449890ddcb2d7.
    [RoboRio Expansion Board V2.sch]
2015-11-07 (re) fixed 3 pin connectors
    Also better layout for the 3v3 regs
    [RoboRio Expansion Board V2.sch]
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2015-11-08 Connected ADCs, removed and replaced led R pack
    [RoboRio Expansion Board V2.sch]
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2015-11-22 Crystal, test points, ADC filters
    Crystal is now SMT, fixed layer issue
    Test points: 5V RR, 5V USB, 3xGND
    ADC filters don't have a value yet, but pieces are in place
    [RoboRio Expansion Board V2.sch]
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2015-11-26 Fixed a bunch of ERC errors
    some weird unconnected wires looked like they were.
    [RoboRio Expansion Board V2.sch]
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2015-11-26 Many small fixes
    MicroSD Symbol
    - layer for >NAME and >VALUE
    ADC
    - origin
    - space for outline
    schematic
    - ADC placement
    - many part names
    - updated ADC and Micro SD
    [RoboRio Expansion Board V2.sch]
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2015-11-28 Updated 3 pin connectors
    Reorganized the set of 12 prop-io 3pins
    other neatening of the schematic
    At this point, there are a few packages that need fixing/updating (see
    google doc todo list), but other than that, the schematic is probably
    ready for a review!
    [RoboRio Expansion Board V2.sch]
2015-11-29 Updates
    Set pwr and gnd in the 3 pin package to be supply pins to avoid errors
    Cleared a bunch of ERC errors.
    [RoboRio Expansion Board V2.sch]
2015-11-29 Fixed PWM 3 pin connections
    Also renamed the RR 3 pin connectors.
    [RoboRio Expansion Board V2.sch]
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2015-12-23 Fixed automatic lock thing
    I don't know why it is there or what purpose it could have.
    [RoboRio Expansion Board V2.sch]
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2015-12-30 Changed Circuitry for LED's on CBUS pins for FT232
    Also added the symbol for the FT231X FT232RL replacement
    [RoboRio Expansion Board V2.sch]
2015-12-30 Revert "Changed Circuitry for LED's on CBUS pins for FT232"
    This reverts commit 5790a9f9b9c9d846d253dddb61c6fedc17bde5e4.
    [RoboRio Expansion Board V2.sch]
2015-12-30 Lots of stuff
    I didn't sync before starting, meaning I crashed github. Now fixed via
    manual save-as, but don't remember everything that was done. Sorry.
    [RoboRio Expansion Board V2.sch]
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2015-12-31 Fixed TPS2115apwr package
    Pins were connecting to the wrong spots
    [RoboRio Expansion Board V2.sch]
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2016-01-01 Power supply passives are placed
    We need to check to see if they are being placed too close together.
    Check the IPC spec.
    [RoboRio Expansion Board V2.brd]
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2016-01-01 Lots more routing
    Yes there are a few loose ends, please don't remove them.
    [RoboRio Expansion Board V2.brd]
2016-01-01 More routing
    Flipped resistor/LED order for the tx/rx indicators
    [RoboRio Expansion Board V2.brd, RoboRio Expansion Board V2.sch]
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2016-01-01 Adjusted 5VUSB so it doesn't cut off ground
    [RoboRio Expansion Board V2.brd]
2016-01-01 Fixed a few small issues
    Also connected reset button.
    [RoboRio Expansion Board V2.brd]
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2016-01-02 Fixed ADC GND/DGND & VA/+3V3 issue
    also lost of routing for the ADCs
    [RoboRio Expansion Board V2.brd, RoboRio Expansion Board V2.sch]
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2016-01-03 reverted pinswaps; sketched out rough idea of new pinswaps
    The IO pins connecting to the Prop should stay constant. The swaps occur
    at the device they are connecting to.
    [RoboRio Expansion Board V2.brd, RoboRio Expansion Board V2.sch]
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2016-01-03 Routed SD card, ADC, connector IO pins
    Power, LCD, and !RESET nets are still incomplete
    [RoboRio Expansion Board V2.brd]
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2016-01-03 Fixed small tps2115 and USB mini error
    Dimension layer was used to draw the outline, but the dimension layer is
    used by Eagle to determine the edge of the board. This meant Eagle
    prevented copper from going near them.
    The USB connector does leave a large clearance around it's holes; this
    *should* go away when we determine how exactly to mount it.
    [RoboRio Expansion Board V2.brd, RoboRio Expansion Board V2.sch]
2016-01-03 Apparently we are breaking a lot of design rules
    Fixed a couple, but have a lot to do.
    [RoboRio Expansion Board V2.brd]
2016-01-03 Attempted to connect LCD 3 pin, broke rules
    [RoboRio Expansion Board V2.brd]
2016-01-03 Revert "Attempted to connect LCD 3 pin, broke rules"
    This reverts commit c6549230bb62e225de526b8d3b2c1519a2f5ed84.
    [RoboRio Expansion Board V2.brd]
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2016-01-03 Fixed overlap errors, dove into clearance issues
    There are some concerning wireing choices, we may need to move
    components
    check google doc todo for more
    [RoboRio Expansion Board V2.brd]
2016-01-04 Fixed small routing issue for LCD connector
    Added a via and rerouted the signal pin to cut off less of the GND
    plane.
    [RoboRio Expansion Board V2.brd]
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2016-01-04 Fixed many DRC errors
    R3 and R15 still need some help, but otherwise this board is getting
    close!
    [RoboRio Expansion Board V2.brd]
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2016-01-08 Switched USB chip to FT231X
    Missing a ferrite bead, currently it's position is held by the capacitor
    named "FERRITEBEAD"
    [RoboRio Expansion Board V2.brd, RoboRio Expansion Board V2.sch]
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2016-01-16 Silk work
    Involved nudging a few components.
    DRC check from 900+ errors to ~490!
    [RoboRio Expansion Board V2.brd]
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2016-01-18 More silk work
    fixed USB connector's lack of >NAME label
    [RoboRio Expansion Board V2.brd, RoboRio Expansion Board V2.sch]
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2016-01-22 Improve power routing
    Please run DRCs in case I introduced routing errors.
    [RoboRio Expansion Board V2.brd]
2016-01-23 Fixed all DRC errors
    Lots of copper movement to deal with clearances, 45° angles, etc.
    [RoboRio Expansion Board V2.brd]
2016-01-23 Fixed stopmask issues with silk
    All that is left is labeling the RR AI/AO in the bottom right, and
    figuring out how to reorient the text for the other connections.
    [RoboRio Expansion Board V2.brd]
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2016-01-26 Run DRC and remove errors
    22 approved errors left. I don't know whey it went down so far from
    235. Still need to add silk for power on 3-pin connectors (which of the
    3 pins are power gnd and signal)
    [RoboRio Expansion Board V2.brd]
2016-01-26 Added Fiducials
    Also fixed a small silk error
    [RoboRio Expansion Board V2.brd, RoboRio Expansion Board V2.sch]
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2016-01-30 SD Card socket fix
    Update library
    rotate 180 deg
    Re-route
    Re-ordered the I/O pins that feed the SD card to remove crossovers
    Changed vias from square to round pads.
    [RoboRio Expansion Board V2.brd, RoboRio Expansion Board V2.sch]
2016-01-30 ERC and DRC fixes
    All minor clearance issues from yesterday
    [RoboRio Expansion Board V2.brd, RoboRio Expansion Board V2.sch]
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2016-01-30 fixed logo BMP, added to center of board
    [RoboRio Expansion Board V2.brd]
2016-01-31 Fixed getSingleAnalogInputVals and worked on the uart connection
    . In the uart connection thing for the propeller, I added the functions
    for the commands for 0x10 through 0x13
    [RR uart connection.spin]
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2016-01-31 Swapped TP Locations
    And some power routing changes.
    [RoboRio Expansion Board V2.brd]
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2016-01-31 Fixed SD card
    Small alignment issue with the fitting nails. Also outline of board was
    slightly off.
    [RoboRio Expansion Board V2.brd, RoboRio Expansion Board V2.sch]
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2016-02-01 Updates to layers for silk, created GERBER cam
    Also fixed the line width for uSD connector outline.
    [RoboRio Expansion Board V2.brd, RoboRio Expansion Board V2.sch]
2016-02-01 small silk, copper changes
    increased size of 5VRR near R28&U7
    adjusted silk to no longer be clipped by vias (L1, C21)
    [RoboRio Expansion Board V2.brd]
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2016-02-04 DIP Switch package and symbol fix
    This should be the final commit on the schematic/board files
    [RoboRio Expansion Board V2.brd, RoboRio Expansion Board V2.sch]
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2016-02-12 Stupid loop in LCD display function in uart connection is not working!
    [RR uart connection.spin]
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2016-02-18 Fixed the set lcd display function on the labview side
    [RR uart connection.spin]
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2016-03-05 The UART connection is not working with the new board
    We think that something is interfering with pins 30 and 31
    [RR uart connection.spin]
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2016-03-09 Fixed UART Connection issue with LED Main
    Also updated pin constants
    [RR uart connection.spin]
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2016-04-01 commented out things that were interfering with the LEDs
    [RR uart connection.spin]
2016-04-01 made labview test for sd logging (still not working)
    [RR uart connection.spin]
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2016-06-27 Was able to open and write to a file through labview
    I partially implemented the new sd controller into uart connection and
    was able to write to a file through the connection with the roborio.
    Still has to be fully implemented into uart connection, and the main
    logging loop for the robot needs to be looked at and fixed to actually
    log things
    [RR uart connection.spin]
2016-07-10 Implemented Set Log Header Function
    0x02
    Also replaced a lot of repeating code with a new handy recieve_string
    function
    [RR uart connection.spin]
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2016-10-20 Fixed some stuff with the led rgb setting. Also added the ability to change led intensity through labview
    [RR uart connection.spin]
2016-12-02 Made some fixes for the UART connectio, and moved all needed labview api files and spin files into a folder
    [RR uart connection.spin]
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2016-12-07 Revert "Merge remote-tracking branch 'refs/remotes/origin/master' into RoboRio-ExpansionBoard-V2"
    This reverts commit fd132cccbfe584e850304a4ab95e8e1d2a821b80, reversing
    changes made to 06a3ab079c7c93978f6e3df025499484c6092760.
    [Main overhaul.spin, RR uart connection.spin]
2016-12-07 Fixed issue with retrieving ADC voltages from board
    had to change the adc.readArray method to just adc.read in the uart
    connection spin file
    [RR uart connection.spin]
2016-12-07 Fix schematic
    DNI C15, C17, fix p/n for U4
    [RoboRio Expansion Board V2.brd, RoboRio Expansion Board V2.sch]
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2016-12-25 Implemented ADC tester method
    It is working pretty well with the current test fixture.
    The only major steps left are to test the SD card, and to write the
    result of all of the tests to the EEPROM memory, so that the following
    boot can skip the tests.
    [ProductionTesterWithMain.spin]
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2017-01-03 Cleaned up dangerous ADC bug
    If the ADC value were to change between reads, it could cause incorrect
    values, since each read was split into an upper half and a lower half.
    Also small changes to the adc controller file.
    [RR uart connection.spin]
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2017-01-03 Massive refactor
    Consolidated, merged, simplified, clarified, overall improved.
    I even fixed a few bugs without even having seen the code in action, now
    that it was easier to read!
    [RR uart connection.spin, main.spin]
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2017-01-03 implemented/defined RequestVersion
    Returns 4 bytes: Major, Minor, Fix, Test.
    [RR uart connection.spin, main.spin]
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2017-01-05 Added restrictions to set_pin_func
    Now only allows certain pins to output, in alignment with Issue #46
    [RR uart connection.spin, main.spin]
2017-01-05 Fixed give_data_func
    It is now deprecated, but I had these fixes ready, so I am applying them
    now.
    [RR uart connection.spin, main.spin]
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2017-01-07 Fixed the jumping samples bug!
    It was a byte mismatch issue. `request_all_analog_func` should probably
    be cleaned up a bit more, but at least now it works!
    [RR uart connection.spin, main.spin]
2017-01-07 Production tester fix
    Implemented the new ADC commands.
    [ProductionTesterWithMain.spin, main.spin]
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

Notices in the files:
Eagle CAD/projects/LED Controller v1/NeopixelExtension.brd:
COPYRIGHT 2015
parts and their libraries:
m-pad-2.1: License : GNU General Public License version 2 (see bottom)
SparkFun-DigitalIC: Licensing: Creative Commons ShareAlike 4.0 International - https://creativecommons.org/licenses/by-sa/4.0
